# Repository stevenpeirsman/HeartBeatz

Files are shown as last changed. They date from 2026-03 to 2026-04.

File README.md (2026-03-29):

# HeartBeatz

**Portable WiFi CSI Sensing Demo Box** — presence detection, pose estimation, and vital signs monitoring using WiFi Channel State Information (CSI), BLE beacons, and mmWave radar.

HeartBeatz packages the [RuView](https://github.com/ruvnet/RuView) sensing platform into a self-contained, battery-powered appliance for client on-site demos. Power on, wait 30 seconds, and the 7" touchscreen walks you through node discovery and room calibration automatically.

---

## Architecture

```
┌─────────────────────────────────────────────────────────────────┐
│  MAIN BOX (MeLE N100 Mini PC)                                  │
│  ┌───────────────────────────────────────────────────────────┐  │
│  │ Docker                                                     │  │
│  │  ┌─────────────────────┐  ┌────────────────────────────┐  │  │
│  │  │ sensing-server      │  │ heartbeatz                  │  │  │
│  │  │ (Rust/Axum)         │  │ (Node.js)                   │  │  │
│  │  │ :3000 REST          │◄─│ :8080 UI + API              │  │  │
│  │  │ :3001 WebSocket     │  │ - Node discovery             │  │  │
│  │  │ :5005 UDP ingest    │  │ - BLE beacon tracking        │  │  │
│  │  └─────────────────────┘  │ - LD2410S radar reader       │  │  │
│  │                            │ - WebSocket hub → UI         │  │  │
│  │                            └────────────────────────────┘  │  │
│  └───────────────────────────────────────────────────────────┘  │
│  IHANFO 7" IPS Display (1024x600, Chromium Kiosk)              │
│  UGREEN 25,000mAh Power Bank                                   │
└────────────────────────┬────────────────────────────────────────┘
                         │ Ethernet (192.168.8.10)
              ┌──────────┴──────────┐
              │ GL.iNet MT3000      │
              │ Router (192.168.8.1)│
              │ SSID: HeartBeatz    │
              └──┬───┬───┬───┬─────┘
                 │   │   │   │  WiFi (192.168.8.x)
          ┌──────┘   │   │   └──────┐
          ▼          ▼   ▼          ▼
     ┌─────────┐┌─────────┐┌─────────┐┌─────────┐
     │ ESP32-S3││ ESP32-S3││ ESP32-S3││ ESP32-S3│
     │ Node 1  ││ Node 2  ││ Node 3  ││ Node 4  │
     │ + Radar ││ + Radar ││ + Radar ││ + Radar │
     │ + UPS   ││ + UPS   ││ + UPS   ││ + UPS   │
     └─────────┘└─────────┘└─────────┘└─────────┘
       CSI + radar data → UDP :5005 → sensing-server
```

## Hardware Bill of Materials

| Component | Model | Qty | Purpose |
|---|---|---|---|
| Mini PC | MeLE Quieter4C (N100, 16GB, 512GB) | 1 | Runs Docker, serves UI |
| Router | GL.iNet MT3000 (Beryl AX) | 1 | Private WiFi for ESP32 nodes |
| Display | IHANFO 7" IPS (HDMI, 1024x600) | 1 | Touchscreen kiosk UI |
| Power Bank | UGREEN 25,000mAh (140W USB-C PD) | 1 | Powers MeLE + display |
| Sensor Node | Heemol ESP32-S3 N16R8 DevKit | 4-5 | WiFi CSI collection |
| Node UPS | TECNOIOT 18650 UPS HAT | 4-5 | Battery backup per node |
| Batteries | 18650 Li-ion cells (3000mAh+) | 8-10 | 2 per node UPS |
| Radar | HLK-LD2410S (24GHz mmWave) | 4-5 | Secondary presence detection |
| BLE Beacons | ABN05 wristbands (nRF52810) | 5-10 | Patient/staff identification |

> **In a hurry?** See [QUICKSTART.md](QUICKSTART.md) for a condensed version. This README is the full reference.

## Quick Start (Demo Mode)

You can run HeartBeatz without any hardware. Demo mode generates realistic simulated data with three built-in scenarios (patient monitoring, fall detection, occupancy tracking).

```bash
# Clone the repository
git clone https://github.com/stevenpeirsman/HeartBeatz.git
cd HeartBeatz

# Start with Docker
docker compose up -d

# Open the UI
open http://localhost:8080
```

The system auto-detects that no ESP32 nodes are reachable and falls back to demo mode. You'll see a "DEMO MODE" banner in the UI with a scenario selector.

To force demo mode explicitly, set `DEMO_MODE=true` in `.env`.

## MeLE N100 Setup (Full Hardware)

Follow these steps in order when setting up the MeLE N100 for the first time.

### Step 1: Install Ubuntu

Install Ubuntu 22.04 LTS (Server or Desktop minimal) on the MeLE N100.

- Use a USB stick with the Ubuntu installer (Rufus or Balena Etcher to create it).
- During install: set hostname to `heartbeatz`, create user `heartbeatz`.
- Choose "Minimal installation" — the kiosk script installs everything else.

After install, connect via keyboard/monitor or SSH and update:

```bash
sudo apt update && sudo apt upgrade -y
```

### Step 2: Install Docker

```bash
# Install Docker
sudo apt install -y docker.io docker-compose
sudo systemctl enable docker
sudo usermod -aG docker heartbeatz

# Log out and back in for group change to take effect
exit
```

Verify Docker works:

```bash
docker run hello-world
```

### Step 3: Clone the Repo

```bash
cd /opt
sudo git clone https://github.com/stevenpeirsman/HeartBeatz.git
sudo chown -R heartbeatz:heartbeatz HeartBeatz
cd HeartBeatz
```

### Step 4: Configure the Network

Connect the MeLE to the GL.iNet router via Ethernet, then run:

```bash
sudo bash system/network-setup.sh
```

This assigns a static IP (`192.168.8.10`) on the router's network. Verify with:

```bash
ping 192.168.8.1    # Should reach the router
ip addr show        # Should show 192.168.8.10
```

### Step 5: Configure the GL.iNet Router

Log into the router admin panel at `http://192.168.8.1`:

1. Set the WiFi SSID to `HeartBeatz` and password to `heartbeatz2026`.
2. Set the WiFi channel to **6** (fixed — must match the ESP32 firmware).
3. Disable band steering and channel auto-selection.
4. Set the DHCP range to `192.168.8.100–192.168.8.199` (keeps `.10` reserved for MeLE).

### Step 6: Start the Services

```bash
cd /opt/HeartBeatz

# Build the Node.js container
docker compose build

# Pull the sensing server image
docker compose pull sensing-server

# Start everything
docker compose up -d

# Verify both containers are healthy
docker compose ps
docker compose logs -f   # Ctrl+C to stop watching
```

Open `http://192.168.8.10:8080` in a browser to verify the UI loads.

### Step 7: Install Kiosk Mode

Once the UI works in a browser, install the kiosk auto-boot service:

```bash
sudo bash system/install-kiosk.sh
```

This does the following:

- Installs X11, Chromium, and display utilities.
- Creates a systemd service (`heartbeatz-kiosk`) that starts on boot.
- Launches Chromium in fullscreen kiosk mode pointing at `http://localhost:3000/setup`.
- Disables desktop login managers (GDM, LightDM).
- Sets up auto-login for the `heartbeatz` user.

Reboot to test:

```bash
sudo reboot
```

The MeLE should boot directly into the HeartBeatz UI on the 7" display.

### Managing the Kiosk

```bash
# Check kiosk status
sudo systemctl status heartbeatz-kiosk

# View kiosk logs
sudo journalctl -u heartbeatz-kiosk -f

# Restart the kiosk (e.g., after a UI update)
sudo systemctl restart heartbeatz-kiosk

# Temporarily disable kiosk (for maintenance)
sudo systemctl stop heartbeatz-kiosk
```

## ESP32-S3 Firmware

Each sensor node runs custom firmware that collects WiFi CSI data and sends it to the sensing server over UDP.

### Prerequisites

Install [PlatformIO](https://platformio.org/install/cli):

```bash
pip install platformio
```

### Build and Flash

```bash
cd firmware

# Build the firmware
pio run

# Flash to a connected ESP32-S3 (USB-C)
pio run --target upload

# Open serial monitor to verify it connects
pio device monitor --baud 115200
```

### What to Expect on Boot

The ESP32 serial output should show:

1. WiFi connecting to SSID `HeartBeatz`...
2. Got IP `192.168.8.1xx`
3. Sending CSI frames to `192.168.8.10:5005` at 50 Hz
4. LED blinks: slow = connecting, solid = streaming, fast = error

### Firmware Configuration

Default values are compile-time flags in `firmware/include/heartbeatz_config.h` (set via `platformio.ini` build flags, **not** `.env`). The key settings:

| Setting | Default | Description |
|---|---|---|
| `HEARTBEATZ_WIFI_SSID` | `HeartBeatz` | Router WiFi SSID |
| `HEARTBEATZ_WIFI_PASS` | `heartbeatz2026` | Router WiFi password |
| `HEARTBEATZ_SERVER_IP` | `192.168.8.10` | MeLE IP (UDP target) |
| `HEARTBEATZ_UDP_PORT` | `5005` | Sensing server UDP port |
| `HEARTBEATZ_CSI_RATE_HZ` | `50` | CSI frame rate |
| `HEARTBEATZ_CHANNEL` | `6` | WiFi channel (must match router) |
| `HEARTBEATZ_RADAR_ENABLED` | `0` | Set to `1` if LD2410S is wired |
| `HEARTBEATZ_POWER_SAVE` | `0` | Set to `1` for battery mode (~10 Hz) |

These can also be overridden at runtime via NVS (Non-Volatile Storage) through the setup wizard.

### Wiring the LD2410S Radar (Optional)

If you attach an LD2410S radar module to a sensor node:

```
ESP32-S3          LD2410S
────────          ───────
GPIO 17 (TX)  →   RX
GPIO 18 (RX)  ←   TX
3.3V          →   VCC
GND           →   GND
```

Set `HEARTBEATZ_RADAR_ENABLED=1` in `platformio.ini` build flags before flashing.

## Configuration Reference

All configuration is in the `.env` file at the project root. Copy `.env` to `.env.local` for site-specific overrides.

### Network

| Variable | Default | Description |
|---|---|---|
| `HEARTBEATZ_IP` | `192.168.8.10` | MeLE static IP |
| `GATEWAY_IP` | `192.168.8.1` | Router IP |
| `SUBNET` | `192.168.8.0/24` | Network subnet |

### Sensing Server

| Variable | Default | Description |
|---|---|---|
| `CSI_SOURCE` | `auto` | `auto`, `esp32`, or `simulated` |
| `SENSING_HTTP_PORT` | `3000` | REST API port |
| `SENSING_WS_PORT` | `3001` | WebSocket port |
| `SENSING_UDP_PORT` | `5005` | ESP32 CSI UDP ingest port |
| `SENSING_TICK_MS` | `100` | Processing tick rate (ms) |

### Node Discovery

| Variable | Default | Description |
|---|---|---|
| `DISCOVERY_INTERVAL_MS` | `5000` | How often to scan for nodes |
| `NODE_TIMEOUT_MS` | `15000` | Mark node offline after this |
| `NODE_SUBNET` | `192.168.8.0/24` | Expected node subnet |

### BLE Beacons

| Variable | Default | Description |
|---|---|---|
| `BLE_ENABLED` | `false` | Enable BLE beacon scanning |
| `BLE_HCI_DEVICE` | `hci0` | Bluetooth adapter (`hci0` = built-in) |
| `BLE_UUID_FILTER` | *(empty)* | iBeacon UUID filter (empty = all) |
| `BLE_RSSI_THRESHOLD` | `-70` | In-room RSSI threshold (dBm) |

### LD2410S Radar

| Variable | Default | Description |
|---|---|---|
| `RADAR_ENABLED` | `false` | Enable radar reading |
| `RADAR_SERIAL_PORT` | *(auto)* | Serial port (auto-detected if empty) |
| `RADAR_BAUD_RATE` | `256000` | LD2410S baud rate |

### Demo Mode

| Variable | Default | Description |
|---|---|---|
| `DEMO_MODE` | `auto` | `true`, `false`, or `auto` (probe server) |
| `DEMO_SCENARIO` | `patient-monitoring` | Starting scenario |

Available scenarios: `patient-monitoring`, `fall-detection`, `occupancy-tracking`.

### Display & Logging

| Variable | Default | Description |
|---|---|---|
| `DISPLAY_WIDTH` | `1024` | Kiosk display width (px) |
| `DISPLAY_HEIGHT` | `600` | Kiosk display height (px) |
| `LOG_LEVEL` | `info` | `debug`, `info`, `warn`, `error` |

## Development

### Running Locally (Without Docker)

```bash
cd server
npm install
npm run dev     # Starts with --watch for auto-reload
```

The UI is served from `ui/` at `http://localhost:8080`. Without a sensing server running, demo mode activates automatically.

### Running Tests

```bash
cd server
npm test
```

Tests cover: config loading, node discovery polling, radar frame parsing, WebSocket event routing, simulator scenarios, and API endpoint validation.

### Project Structure

```
HeartBeatz/
├── docker-compose.yml      # Runs sensing-server + heartbeatz containers
├── .env                    # All configuration with defaults
├── server/                 # Node.js orchestration layer
│   ├── Dockerfile
│   ├── package.json
│   └── src/
│       ├── index.js        # Entry point — boots all subsystems
│       ├── config.js       # Environment + persistent state
│       ├── discovery.js    # Polls sensing server for ESP32 nodes
│       ├── ble-scanner.js  # iBeacon/Eddystone tracking (Linux)
│       ├── radar.js        # LD2410S mmWave UART reader
│       ├── simulator.js    # Demo mode data generator (3 scenarios)
│       ├── websocket.js    # WS hub — enriches + broadcasts to UI
│       └── routes/
│           └── api.js      # REST endpoints (health, nodes, beacons, etc.)
├── ui/                     # Kiosk touchscreen interface
│   ├── index.html          # Splash → Setup Wizard → Live Dashboard
│   ├── css/app.css
│   └── js/
│       ├── app.js          # State machine + WebSocket client
│       └── room-map.js     # Canvas room visualization (12 layers)
├── firmware/               # ESP32-S3 PlatformIO project
│   ├── platformio.ini
│   ├── partitions.csv
│   └── include/
│       └── heartbeatz_config.h
├── system/                 # Linux system setup scripts
│   ├── install-kiosk.sh    # Configures auto-boot Chromium kiosk
│   └── network-setup.sh    # Static IP on GL.iNet network
└── cadquery/               # 3D enclosure STEP files
```

## Boot Sequence

When the MeLE powers on, here's what happens:

1. **systemd** starts the `heartbeatz-kiosk` service.
2. **Docker Compose** starts `sensing-server` (Rust) and `heartbeatz` (Node.js).
3. The kiosk script waits up to 120 seconds for the sensing server health check.
4. **Chromium** launches in fullscreen kiosk mode at `http://localhost:3000/setup`.
5. The **Splash Screen** shows a progress bar while polling `/api/health`.
6. Once ready, the **Setup Wizard** starts node discovery (polling `/api/nodes`).
7. After nodes are found, the wizard runs a 10-second **room calibration**.
8. The **Live Dashboard** opens with real-time vital signs, room map, and beacon tracking.

If the sensing server is unreachable, the system falls into demo mode with simulated data.

## Troubleshooting

### No ESP32 Nodes Detected

- Verify the router WiFi SSID is exactly `HeartBeatz` (case-sensitive) and the channel is **6**.
- Check that the ESP32 got an IP: open the serial monitor (`pio device monitor`).
- Ensure the MeLE firewall allows UDP on port 5005: `sudo ufw status`.
- Check the sensing server logs: `docker compose logs sensing-server`.

### UI Shows "Connecting..." Indefinitely

- Verify both containers are running: `docker compose ps`.
- Check the heartbeatz container logs: `docker compose logs heartbeatz`.
- Test the API directly: `curl http://localhost:8080/api/health`.

### Demo Mode Activates When It Shouldn't

- The sensing server container may still be starting. Check its health: `docker compose ps`.
- Wait for the healthcheck to pass (up to 15 seconds after container start).
- Set `DEMO_MODE=false` in `.env` to force real mode (will show errors if server is down).

### Kiosk Display Issues

- If the display is blank, check `sudo systemctl status heartbeatz-kiosk`.
- The IHANFO display works over HDMI with no special drivers. Ensure the HDMI cable is connected before boot.
- For display resolution issues, verify `DISPLAY_WIDTH=1024` and `DISPLAY_HEIGHT=600` in `.env`.

### BLE Beacons Not Showing

- BLE is disabled by default. Set `BLE_ENABLED=true` in `.env`.
- BLE scanning requires host network mode. Uncomment `network_mode: host` in `docker-compose.yml`.
- Verify the Bluetooth adapter: `hcitool dev` (should show `hci0`).

### Radar Not Reading

- Radar is disabled by default. Set `RADAR_ENABLED=true` in `.env`.
- Uncomment the `devices` section in `docker-compose.yml` to pass through `/dev/ttyUSB0`.
- Check serial port: `ls /dev/ttyUSB*` or `ls /dev/ttyACM*`.

## License

Private project. Not for redistribution.

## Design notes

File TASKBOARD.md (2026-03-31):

# HeartBeatz Development Task Board
<!-- Single source of truth for all agent coordination -->
<!-- Updated by: architect (assigns), workers (status), reviewer (feedback) -->

## Active Sprint: Sprint 1 — Foundation & Infrastructure

**Sprint Goal:** Build feature extraction pipeline, ground truth system, adaptive baseline improvements, database layer, and admin module foundation. Establish engineering infrastructure for all accuracy and platform work.

**Sprint Start:** 2026-03-31
**Sprint End:** 2026-04-14

---

## Task Assignment Matrix

### ACC-01: Feature Extraction Pipeline (worker-alpha)

| Task ID | Title | Status | Branch | Priority | Est |
|---|---|---|---|---|-----|
| ACC-01-T1 | Implement subcarrier grouping into 8 logical bands (guard/pilot/data) | approved | feat/subcarrier-grouping | P0 | 2h |
| ACC-01-T2 | Add phase difference extraction with linear unwrapping | approved | feat/phase-extraction | P0 | 3h |
| ACC-01-T3 | Implement short-time FFT for Doppler motion classification (breathing 0.2-0.5Hz, walking 1-3Hz) | approved | feat/doppler-fft | P0 | 4h |
| ACC-01-T4 | Add statistical features: mean, variance, kurtosis, skewness, IQR, entropy per window | approved | feat/stat-features | P1 | 3h |
| ACC-01-T5 | Implement subcarrier correlation matrix with eigenvalue spread metric | approved | feat/corr-matrix | P1 | 3h |
| ACC-01-T6 | Build frame quality scorer (RSSI stability, timestamp jitter, packet loss) | approved | feat/frame-quality | P1 | 2h |
| ACC-01-T7 | Create feature vector serializer (JSON for SSE, CSV export for ML training) | approved | feat/feature-serializer | P1 | 2h |
| ACC-01-T8 | Add /api/v1/features endpoint returning current feature vectors per node | approved | feat/features-api | P1 | 1h |
| ACC-01-T9 | Add /api/v1/features/stream SSE endpoint at 5Hz | approved (merged with T8) | feat/features-api | P1 | 1h |

### ACC-03: Adaptive Baseline Calibration (worker-beta)

| Task ID | Title | Status | Branch | Priority | Est |
|---|---|---|---|---|-----|
| ACC-03-T1 | Implement multi-timescale baseline tracking (fast alpha=0.1/30s, medium alpha=0.01/5min, slow alpha=0.001/1hr) | approved | feat/multi-timescale-baseline | P0 | 3h |
| ACC-03-T2 | Add CUSUM environment change detection on per-subcarrier residuals | approved | feat/cusum-detection | P0 | 3h |
| ACC-03-T3 | Build automatic empty-room detection heuristic (variance < 1.2x baseline for >10min) | approved | feat/empty-room-detect | P0 | 2h |
| ACC-03-T4 | Implement baseline persistence to disk (save hourly + on shutdown, load on restart) | approved | feat/baseline-persist | P1 | 2h |
| ACC-03-T5 | Add recalibration event structured logging with shift magnitude and trigger type | in-review | feat/recal-logging | P1 | 1h |
| ACC-03-T6 | Create /api/v1/calibration/history endpoint returning last 100 recal events | in-review | feat/cal-history-api | P1 | 1h |
| ACC-03-T7 | Implement diurnal drift model (temperature correlation) | backlog | feat/diurnal-model | P2 | 3h |

### ACC-08: Ground Truth System (worker-gamma)

| Task ID | Title | Status | Branch | Priority | Est |
|---|---|---|---|---|-----|
| INFRA-01 | Add better-sqlite3 dependency and create database init module (auto-create tables on start) | approved | feat/sqlite-init | P0 | 2h |
| INFRA-02 | Create shared constants module: subcarrier count, frame sizes, feature names enum | approved | feat/shared-types | P0 | 1h |
| ACC-08-T1 | Build /api/v1/ground-truth POST endpoint (accepts {true_count, annotator, session_id}) | approved | feat/ground-truth-api | P0 | 2h |
| ACC-08-T2 | Build label collection web UI: large 0/1/2/3+ buttons, SSE live context, keyboard shortcuts | approved | feat/ground-truth-ui | P0 | 3h |
| ACC-08-T3 | Implement CSI-label alignment: match labels to nearest CSI frame by timestamp within 100ms | in-review | feat/label-alignment | P1 | 2h |
| ACC-08-T4 | Create automated evaluation pipeline: confusion matrix, precision/recall/F1, per-class breakdown | in-review | feat/eval-pipeline | P1 | 4h |
| ACC-08-T5 | Build /api/v1/evaluation/report endpoint returning latest accuracy metrics | approved | feat/eval-report-api | P1 | 1h |
| ACC-08-T6 | Implement labeling session management (start/stop/list sessions with metadata) | backlog | feat/label-sessions | P2 | 2h |
| ACC-08-T7 | Add CSV/JSON bulk export of labeled dataset via /api/v1/ground-truth/export | backlog | feat/gt-export | P2 | 1h |

### ADMIN: Node Management Module (worker-gamma)

| Task ID | Title | Status | Branch | Priority | Est |
|---|---|---|---|---|-----|
| ADMIN-01 | Create nodes database table (id, mac, name, ip, type, firmware_version, status, last_seen, position_x, position_y) | approved | feat/nodes-db | P0 | 2h |
| ADMIN-02 | Build /api/v1/nodes CRUD endpoints (list, get, create, update, delete) | approved | feat/nodes-crud-api | P0 | 3h |
| ADMIN-03 | Build node admin web UI: list nodes, add/edit name, delete, show status/firmware/last_seen | in-review | feat/nodes-admin-ui | P0 | 4h |
| ADMIN-04 | Integrate discovery service with nodes DB: auto-register discovered ESP32 nodes, update last_seen | approved | feat/nodes-discovery-sync | P1 | 2h |
| ADMIN-05 | Add firmware flash endpoint /api/v1/nodes/:id/flash (upload .bin, SSH to MeLE, esptool flash) | backlog | feat/nodes-firmware-flash | P1 | 4h |
| ADMIN-06 | Add node numbering/ordering system with drag-and-drop reorder in admin UI | backlog | feat/nodes-ordering | P2 | 2h |
| ADMIN-07 | Add node health check endpoint /api/v1/nodes/:id/ping (check reachability, get firmware version) | in-review | feat/nodes-health-api | P1 | 1h |

### SENSOR: LD2410S Radar Integration (worker-beta)

| Task ID | Title | Status | Branch | Priority | Est |
|---|---|---|---|---|-----|
| SENSOR-01 | Complete LD2410S UART parser for engineering mode frames (extend existing radar.js) | approved | feat/radar-parser | P0 | 3h |
| SENSOR-02 | Add radar data to SSE stream alongside CSI data (unified sensor event model) | in-review | feat/radar-sse | P1 | 2h |
| SENSOR-03 | Build radar configuration API: set detection gates, sensitivity thresholds, engineering mode toggle | backlog | feat/radar-config-api | P1 | 2h |
| SENSOR-04 | Implement CSI + radar fusion: use radar distance + energy as validation for CSI person detection | backlog | feat/csi-radar-fusion | P1 | 4h |
| SENSOR-05 | Add radar presence data to ground truth comparison (radar as secondary ground truth source) | backlog | feat/radar-ground-truth | P2 | 2h |
| SENSOR-06 | Create radar diagnostic dashboard: live distance/energy charts, detection state, gate visualization | backlog | feat/radar-dashboard | P2 | 3h |

### SENSOR: BLE Beacon Integration (worker-beta)

| Task ID | Title | Status | Branch | Priority | Est |
|---|---|---|---|---|-----|
| BLE-01 | Complete BLE scanner hcitool/hcidump integration for iBeacon parsing (extend existing ble-scanner.js) | approved | feat/ble-scanner-complete | P0 | 3h |
| BLE-02 | Add BLE beacon registry DB table (mac, uuid, major, minor, name, role, battery_level, last_seen) | backlog | feat/ble-registry-db | P1 | 2h |
| BLE-03 | Build beacon management admin UI: list beacons, assign names/roles (patient/staff/equipment) | backlog | feat/ble-admin-ui | P1 | 3h |
| BLE-04 | Implement RSSI-to-zone mapping: configurable RSSI thresholds per zone for proximity detection | backlog | feat/ble-zone-mapping | P1 | 3h |
| BLE-05 | Build CSI + BLE identity fusion: CSI detects "someone is here", BLE identifies "who is here" | backlog | feat/csi-ble-fusion | P1 | 4h |
| BLE-06 | Add BLE sighting data to SSE stream with identity resolution | backlog | feat/ble-sse | P2 | 1h |
| BLE-07 | Implement beacon battery monitoring with low-battery alerts | backlog | feat/ble-battery-alerts | P2 | 2h |

### DB: Database & Persistence Layer (worker-gamma)

| Task ID | Title | Status | Branch | Priority | Est |
|---|---|---|---|---|-----|
| DB-01 | Design unified SQLite schema: nodes, sensors, events, labels, evaluations, metrics, sessions | approved | feat/db-schema | P0 | 3h |
| DB-02 | Implement database migration system (version-tracked schema changes) | approved | feat/db-migrations | P1 | 2h |
| DB-03 | Build event storage: all detection events persisted with timestamp, node, count, confidence, features hash | in-review | feat/event-storage | P1 | 2h |
| DB-04 | Add metrics storage: hourly aggregates of accuracy, detection rate, false positive rate, latency | backlog | feat/metrics-storage | P1 | 2h |
| DB-05 | Create /api/v1/metrics endpoint: query accuracy trends, compare algorithm versions, time-range filter | backlog | feat/metrics-api | P1 | 2h |
| DB-06 | Implement data retention policy: raw events (30 days), aggregates (1 year), configurable via env vars | backlog | feat/data-retention | P2 | 2h |
| DB-07 | Add improvement tracking table: version, algorithm_config, accuracy_metrics, timestamp, notes | backlog | feat/improvement-tracking | P1 | 2h |
| DB-08 | Build /api/v1/improvements endpoint: log each algorithm change with before/after accuracy metrics | backlog | feat/improvements-api | P2 | 1h |

### UX: Frontend Dashboard & Visualization (worker-alpha)

| Task ID | Title | Status | Branch | Priority | Est |
|---|---|---|---|---|-----|
| UX-01 | Create main dashboard shell: responsive layout with sidebar nav, header, content area (HTML/CSS/JS) | backlog | feat/dashboard-shell | P0 | 4h |
| UX-02 | Build real-time overview panel: per-node person count, EMA, variance, confidence badges, trend sparklines | backlog | feat/overview-panel | P0 | 3h |
| UX-03 | Create zone/floor plan view: SVG overlay with colored zones, occupancy counts, click for zone detail | backlog | feat/floorplan-view | P1 | 5h |
| UX-04 | Build node status panel: list all ESP32 nodes, LD2410S radars, BLE scanners with health indicators | backlog | feat/node-status-panel | P1 | 2h |
| UX-05 | Create CSI feature heatmap v2: improved layout from dev-heatmap, add feature vector visualization | backlog | feat/heatmap-v2 | P1 | 3h |
| UX-06 | Build accuracy tracking dashboard: line charts of accuracy over time, confusion matrix visualization | backlog | feat/accuracy-dashboard | P1 | 3h |
| UX-07 | Create alert panel: live alerts for wandering, dwell-time, low battery, node offline, accuracy drop | backlog | feat/alert-panel | P2 | 3h |
| UX-08 | Add dark mode toggle and responsive mobile/tablet layout | backlog | feat/responsive-dark | P2 | 2h |
| UX-09 | Build settings page: configure thresholds, node positions, zone boundaries, alert rules | backlog | feat/settings-page | P2 | 4h |

### KPI: Hospital ED Metrics & Analytics (worker-gamma)

| Task ID | Title | Status | Branch | Priority | Est |
|---|---|---|---|---|-----|
| KPI-01 | Implement zone dwell-time tracker: per-zone timers with configurable alert thresholds | backlog | feat/dwell-time-tracker | P1 | 3h |
| KPI-02 | Build door-to-triage time estimator: detect entry zone → triage zone transition, compute duration | backlog | feat/door-to-triage | P1 | 3h |
| KPI-03 | Implement patient throughput counter: zone transitions per hour, daily totals, rolling averages | backlog | feat/throughput-counter | P1 | 2h |
| KPI-04 | Add LWBS (left without being seen) detection: entry zone dwell > threshold then exit without treatment zone visit | backlog | feat/lwbs-detection | P2 | 3h |
| KPI-05 | Build ED analytics dashboard: door-to-triage, dwell times, throughput, occupancy trends, LWBS rate | backlog | feat/ed-analytics | P2 | 5h |
| KPI-06 | Implement shift handoff report: auto-generated summary at shift change with zone status, pending patients, alerts | backlog | feat/shift-handoff | P2 | 3h |
| KPI-07 | Add nurse call integration hooks: webhook receiver for nurse call events, correlate with location data | backlog | feat/nurse-call-hooks | P3 | 3h |
| KPI-08 | Build bed management status: auto-detect room occupancy state (empty/occupied/cleaning) from CSI patterns | backlog | feat/bed-management | P2 | 4h |

### ACC-02: ML Classifier (worker-alpha) — Sprint 2+

| Task ID | Title | Status | Branch | Priority | Est |
|---|---|---|---|---|-----|
| ACC-02-T1 | Design labeled data collection protocol: annotation schema, activity types, collection UI integration | backlog | feat/ml-data-protocol | P1 | 2h |
| ACC-02-T2 | Build training data pipeline: stream features to labeled SQLite dataset, support manual annotation | backlog | feat/ml-training-pipeline | P1 | 4h |
| ACC-02-T3 | Install ONNX Runtime for Node.js on MeLE N100, verify performance | backlog | feat/onnx-setup | P1 | 2h |
| ACC-02-T4 | Train Random Forest classifier (200 trees, max_depth=12) with feature importance analysis | backlog | feat/ml-random-forest | P1 | 5h |
| ACC-02-T5 | Implement A/B comparison mode: run threshold-based + ML in parallel, log both, compare in dashboard | backlog | feat/ml-ab-compare | P1 | 3h |
| ACC-02-T6 | Build model evaluation framework: confusion matrix, per-class P/R/F1, ROC curves, auto-report | backlog | feat/ml-eval-framework | P2 | 3h |
| ACC-02-T7 | Implement online learning: high-confidence predictions auto-label, nightly retrain trigger | backlog | feat/ml-online-learning | P2 | 4h |
| ACC-02-T8 | Add model versioning: store model artifacts, config, metrics per version, rollback support | backlog | feat/ml-versioning | P2 | 2h |

### ACC-06: Breathing & Vital Signs (worker-alpha) — Sprint 2+

| Task ID | Title | Status | Branch | Priority | Est |
|---|---|---|---|---|-----|
| ACC-06-T1 | Implement Butterworth IIR bandpass filter bank: breathing (0.1-0.5Hz), heart (0.8-2.0Hz) | backlog | feat/bandpass-filters | P1 | 3h |
| ACC-06-T2 | Add harmonic rejection via comb filter to prevent breathing rate doubling | backlog | feat/harmonic-rejection | P1 | 2h |
| ACC-06-T3 | Implement multi-subcarrier voting: median of per-band estimates, confidence = agreement ratio | backlog | feat/vital-voting | P1 | 2h |
| ACC-06-T4 | Add motion gating: suspend vital estimation when gross motion > 5x breathing threshold | backlog | feat/motion-gating | P1 | 1h |
| ACC-06-T5 | Build signal quality metric (0-1): SNR, autocorrelation prominence, subcarrier agreement | backlog | feat/vital-quality | P1 | 2h |
| ACC-06-T6 | Implement Kalman filter for continuous breathing rate tracking | backlog | feat/vital-kalman | P2 | 3h |

### ACC-09: State Machine & Temporal Smoothing (worker-beta) — Sprint 2+

| Task ID | Title | Status | Branch | Priority | Est |
|---|---|---|---|---|-----|
| ACC-09-T1 | Design state machine model: EMPTY/OCCUPIED_1/2/3+/TRANSITIONING with transition constraints | backlog | feat/state-machine-model | P1 | 2h |
| ACC-09-T2 | Implement HMM smoother: emission from ML confidence, transition matrix encoding physical plausibility | backlog | feat/hmm-smoother | P1 | 4h |
| ACC-09-T3 | Add configurable hysteresis: different thresholds for entering vs leaving occupied state | backlog | feat/hysteresis | P1 | 2h |
| ACC-09-T4 | Implement transition event emitter: {from_state, to_state, timestamp, confidence, duration_ms} | backlog | feat/transition-events | P1 | 1h |
| ACC-09-T5 | Build anti-flicker median filter (window=7) combined with state machine | backlog | feat/anti-flicker | P1 | 1h |

### ACC-04: Spatial Fusion (worker-alpha) — Sprint 3+

| Task ID | Title | Status | Branch | Priority | Est |
|---|---|---|---|---|-----|
| ACC-04-T1 | Implement node topology model: node positions in room coordinates, config file schema | backlog | feat/node-topology | P1 | 2h |
| ACC-04-T2 | Build probabilistic occupancy grid: 1m x 1m cells, P(occupied | CSI observations) per cell | backlog | feat/occupancy-grid | P1 | 5h |
| ACC-04-T3 | Implement Bayesian sensor fusion across nodes with temporal motion prior | backlog | feat/bayesian-fusion | P1 | 4h |
| ACC-04-T4 | Add zone entry/exit event detection with 5-second hysteresis | backlog | feat/zone-events | P1 | 2h |
| ACC-04-T5 | Build graceful degradation on node failure: widen uncertainty, reweight remaining nodes | backlog | feat/node-degradation | P2 | 2h |
| ACC-04-T6 | Add spatial consistency cross-validation between nodes | backlog | feat/spatial-consistency | P2 | 2h |

### ACC-07: Interference Rejection (worker-beta) — Sprint 3+

| Task ID | Title | Status | Branch | Priority | Est |
|---|---|---|---|---|-----|
| ACC-07-T1 | Implement spectral interference detector: flag frames with >25% subcarrier deviation | backlog | feat/interference-detect | P1 | 3h |
| ACC-07-T2 | Build adaptive frame quality filter combining RSSI, amplitude distribution, phase coherence | backlog | feat/quality-filter | P1 | 3h |
| ACC-07-T3 | Add static multipath estimation during calibration, subtract from live observations | backlog | feat/multipath-subtract | P1 | 3h |
| ACC-07-T4 | Implement channel change detection (distinguish channel hop from human movement) | backlog | feat/channel-detect | P2 | 2h |
| ACC-07-T5 | Build interference statistics dashboard widget | backlog | feat/interference-stats | P2 | 2h |

### TECH-DEBT: Code Quality Cleanup (any worker with capacity)

| Task ID | Title | Status | Branch | Priority | Est |
|---|---|---|---|---|-----|
| DEBT-01 | Extract shared _ema() helper from multi-timescale.js and cusum.js into shared/math-utils.js | in-review | feat/shared-ema | P1 | 0.5h |
| DEBT-02 | Remove dead `activeThreshold` variable in empty-room.js (line ~193) | in-review | feat/cleanup-empty-room | P1 | 0.5h |
| DEBT-03 | Add pino logging to empty-room.js and doppler.js on state transitions | in-review (empty-room.js done, doppler.js → worker-alpha) | feat/add-logging | P1 | 1h |
| DEBT-04 | Verify ground-truth.html transport: WebSocket vs SSE — standardize to match project conventions | in-review | feat/gt-transport-fix | P1 | 1h |

**Architect assignment (2026-03-31):** DEBT-01 + DEBT-02 → worker-beta (owns calibration modules); DEBT-03 → split: empty-room.js logging → worker-beta, doppler.js logging → worker-alpha; DEBT-04 → worker-gamma (owns ground-truth UI). Workers: pick these up as gap-fillers between main tasks — they're fast wins that clean up reviewer-flagged issues.

### RTLS: Zone & Flow Management — Sprint 3+

| Task ID | Title | Status | Branch | Priority | Est |
|---|---|---|---|---|-----|
| RTLS-01-T1 | Build floor plan upload/calibration: web UI for PNG/SVG upload, scale setting, origin point | backlog | feat/floorplan-upload | P1 | 3h |
| RTLS-01-T2 | Implement zone drawing tool: canvas polygon drawing, edit, assign properties (name, type, color) | backlog | feat/zone-drawing | P1 | 5h |
| RTLS-01-T3 | Build node-to-zone assignment: drag nodes onto floor plan, store mapping in DB | backlog | feat/node-zone-assign | P1 | 3h |
| RTLS-01-T4 | Implement zone adjacency auto-detection from polygon boundaries | backlog | feat/zone-adjacency | P2 | 2h |
| RTLS-02-T1 | Implement per-zone occupancy state machine using ACC-09 per zone | backlog | feat/zone-state | P1 | 3h |
| RTLS-02-T2 | Build event stream: ZONE_ENTER, ZONE_EXIT, COUNT_CHANGE, DWELL_ALERT via SSE | backlog | feat/zone-events-sse | P1 | 2h |
| RTLS-02-T3 | Implement anonymous journey tracking: aggregate flow stats per zone without individual attribution | backlog | feat/anon-journey | P2 | 3h |
| RTLS-02-T4 | Build historical flow replay: slider to replay zone occupancy over past periods | backlog | feat/flow-replay | P2 | 4h |

### GDPR: Privacy & Compliance — Sprint 2+

| Task ID | Title | Status | Branch | Priority | Est |
|---|---|---|---|---|-----|
| GDPR-01 | Implement audit logging: immutable append-only log of all API access with hash chain | backlog | feat/audit-log | P1 | 3h |
| GDPR-02 | Build data anonymization layer: hash all patient/person references with rotating salt | backlog | feat/anonymization | P1 | 2h |
| GDPR-03 | Implement right-to-erasure: delete all records for a given pseudonym across all tables | backlog | feat/data-erasure | P2 | 2h |
| GDPR-04 | Add data minimization configuration: toggle what data is collected/retained per privacy level | backlog | feat/data-minimization | P2 | 2h |

### INTEGRATION: External Systems — Sprint 4+

| Task ID | Title | Status | Branch | Priority | Est |
|---|---|---|---|---|-----|
| INT-01 | Design EHR adapter interface: abstract class with sendLocationEvent(), queryPatientContext() | backlog | feat/ehr-adapter | P1 | 2h |
| INT-02 | Implement HL7 FHIR adapter: map zone events to FHIR Location/Encounter resources | backlog | feat/fhir-adapter | P2 | 4h |
| INT-03 | Build event queue with retry: SQLite-backed persistent queue, exponential backoff | backlog | feat/event-queue | P1 | 3h |
| INT-04 | Create data export pipeline: hourly Parquet/CSV export for data warehouse | backlog | feat/data-export | P2 | 3h |
| INT-05 | Build MQTT broker integration for IoT interop (sensor data, alerts, commands) | backlog | feat/mqtt-broker | P2 | 3h |
| INT-06 | Add webhook dispatcher for external notifications (dwell alerts, count changes, zone events) | backlog | feat/webhook-dispatch | P2 | 2h |

---

## Agent Roles

### worker-alpha (Signal Processing & UX Specialist)
**Focus:** CSI signal processing, feature extraction, spectral analysis, frontend visualization
**Current Sprint:** ACC-01 (Feature Extraction) + start UX foundation
**Skills:** DSP, FFT, filtering, subcarrier analysis, HTML/CSS/JS dashboards

### worker-beta (Calibration, Sensors & Robustness Engineer)
**Focus:** Baseline management, LD2410S radar, BLE beacons, sensor fusion, environment adaptation
**Current Sprint:** ACC-03 (Adaptive Baseline) + SENSOR (LD2410S/BLE start)
**Skills:** Statistical methods, CFAR, UART protocols, BLE, sensor fusion

### worker-gamma (Infrastructure, Data & Admin Engineer)
**Focus:** Database, APIs, ground truth, evaluation, admin module, hospital KPIs
**Current Sprint:** ACC-08 (Ground Truth) + INFRA + ADMIN + DB foundation
**Skills:** REST APIs, SQLite, web UIs, testing frameworks, data pipelines

---

## Review Queue

**⚡ Architect Note (2026-03-31 evening):** 6 items pending review — this is the sprint's primary bottleneck. Reviewer should process in the priority order below. Items are ordered by dependency chain: ACC-03-T4 and ADMIN-03 unblock nothing directly but validate persistence and admin foundations; ACC-08-T3/T4/T5 form a dependency chain (alignment → evaluator → eval-api). SENSOR-01 can be reviewed independently.

**Recommended review order:** ACC-03-T4 → SENSOR-01 → ADMIN-03 → ACC-08-T3 → ACC-08-T4 → ACC-08-T5

| Task ID | Branch | Worker | Review Status | Reviewer Notes |
|---|---|---|---|---|
| INFRA-02 | feat/shared-types | worker-alpha | **approved** | Clean foundation. Excellent docs with physical meaning/units. Frozen objects for immutability. 30 tests pass. Suggestion: add @enum annotations to band labels. |
| ACC-01-T1 | feat/subcarrier-grouping | worker-alpha | **approved** | Well-written pure functions. groupSubcarriers correctly validates + computes per-band/cross-band stats. Note: slice() in groupSubcarriers allocates per band per frame — acceptable at 8×7 elements on N100 but flag if profiling shows pressure. 22 tests pass. |
| ACC-01-T2 | feat/phase-extraction | worker-alpha | **approved** | **Excellent work.** Outstanding physics-based docs. unwrapPhase handles NaN gaps correctly. fitLinearPhase uses Bessel-corrected residualStd with n-2 (correct for 2-param model). wrapToPi handles arbitrary 2π multiples. 32 tests pass with comprehensive edge cases. |
| ACC-03-T1 | feat/multi-timescale-baseline | worker-beta | **approved** | Solid design. Sigmoid blending is elegant — weights sum to 1.0 at all interpolation points. State persistence clean. Rate-limiting good for N100. 19 tests pass. Minor: _ema() duplicated in cusum.js — extract to shared utility when convenient. |
| ACC-03-T2 | feat/cusum-detection | worker-beta | **approved** | Textbook two-sided CUSUM with proper references (Page 1954, Lucas & Crosier 1982). Channel voting robust against single-subcarrier glitches. FIR headstart, adaptive running std via MAD estimator (sqrt(π/2)) correct. Float64Array good for perf. 25 tests pass. Same _ema() duplication note. |
| INFRA-01 | feat/sqlite-init | worker-gamma | **approved** | Solid singleton pattern. WAL mode, foreign keys, busy_timeout all correct. Migration in transaction for atomicity. _resetDbSingleton for testing is good practice. inMemory mode for test isolation. 10 tests pass. Suggestion: add verbose_errors pragma for better debugging in dev. |
| DB-01 | feat/db-schema | worker-gamma | **approved** | Unified schema covers all planned modules (7 tables + 6 indexes). Version tracking via user_version is clean. Index choices match expected query patterns. Schema is embedded in INFRA-01's db/index.js — good single-file approach for PoC. |
| ACC-08-T1 | feat/ground-truth-api | worker-gamma | **approved** | Clean REST API following project conventions ({ok, data} responses). Good input validation in POST /labels: checks session exists AND is active, validates true_count range. Correct HTTP status codes (201 create, 400 validation, 404 not found, 409 conflict). Pagination support. 19 tests pass with good coverage of happy/error paths. |
| ACC-08-T2 | feat/ground-truth-ui | worker-gamma | **approved** | Well-structured labeling UI. Large touch-friendly buttons, keyboard shortcuts (0-3, S, E), live CSI context sidebar, label history. Session management flow is complete. CSS-only animations for feedback. Matches dev-heatmap.html aesthetic. Note: uses WebSocket but task description says SSE — verify which transport is correct for live context (not a blocker, both work). |
| ADMIN-01 | feat/nodes-db | worker-gamma | **approved** | Nodes table schema is complete: all specified columns present, MAC uniqueness enforced, REAL types for position coords, created_at/updated_at with datetime defaults. Part of DB-01 unified schema. 9 tests pass including constraint enforcement. |
| ADMIN-02 | feat/nodes-crud-api | worker-gamma | **approved** | Full CRUD with proper validation: MAC format regex, duplicate detection (409), partial update via dynamic SQL builder, allowed-fields whitelist prevents injection. Consistent with project API conventions. Note: PUT dynamic SQL builder constructs query from allowed list — safe pattern. |
| ACC-03-T3 | feat/empty-room-detect | worker-beta | **approved** | Well-designed Schmitt-trigger hysteresis. Clean sliding window with 10% transient spike tolerance for HVAC. State persistence via getState/restoreState. Excellent JSDoc with CFAR reference. 31 tests pass. Minor: `activeThreshold` (line 193) is computed but unused — isQuiet always uses varianceRatioThreshold; hysteresis is correctly handled in _evaluateState() so not a bug, just dead code — remove it. `_observations.shift()` in while loop is O(n) but acceptable at ≤720 entries. Suggestion: add pino logging on state transitions. |
| ACC-01-T3 | feat/doppler-fft | worker-alpha | **approved** | **Excellent work.** Pure-JS radix-2 FFT with no external deps — ideal for N100 portability. Hann window caching smart for hot-path. Clean pure function / stateful class separation. Doppler bands with physical descriptions are exemplary. 52 tests with known-signal verification. Circular buffer in DopplerAnalyzer handles wrap correctly. 52×64-pt FFT ≈ 0.2ms — well within budget. Classification thresholds well-chosen for 8-bit I/Q. Suggestion: add pino logging to DopplerAnalyzer for state transitions; consider exposing per-subcarrier spectra for debugging. |
| ADMIN-03 | feat/nodes-admin-ui | worker-gamma | **changes-requested** | CRUD, MAC validation, keyboard shortcuts all correct. Two fixes needed: (1) Font family mismatch — uses 'Courier New' instead of 'SF Mono', 'Fira Code', 'Consolas' matching dev-heatmap.html; update line 20. (2) Toast name bug — when creating node without name, toast shows "undefined" instead of MAC; fix line 708 to use `data.name \|\| macInput.value`. |
| ACC-03-T4 | feat/baseline-persist | worker-beta | **approved** | **Excellent work.** Production-ready persistence with correct atomic write (temp+rename), per-module error isolation, version-checked loading, and staleness detection. Immutable DEFAULT_CONFIG, fallback logger, diagnostic getStatus(). 41 tests cover full cycle, module failures, corrupted files, version mismatches, stale state. Suggestion: extract MODULE_KEYS as a constant (line 375) for future extensibility. |
| ACC-08-T3 | feat/label-alignment | worker-gamma | **changes-requested** | Functionally correct alignment with good UTC handling and tolerance boundaries. Three fixes needed: (1) Misleading docs — header claims "binary search" but implementation uses two ORDER BY+LIMIT queries; update to "indexed range queries". (2) Missing input validation — add sessionId format check and maxDeltaMs ≥ 0 validation. (3) Extract repeated strftime format string '%Y-%m-%d %H:%M:%f' (appears 8 times) to a module-level constant TIMESTAMP_FORMAT. Also: add a SQLite datetime format test (space-separated, no 'Z') and strengthen confidence filter test (verify filtered < unfiltered). |
| ACC-01-T4 | feat/stat-features | worker-alpha | **approved** | **Excellent work.** All formulas correct: Fisher-Pearson skewness with n/((n-1)(n-2)) correction, Bessel-corrected variance, linear interpolation quantile matching NumPy, Shannon entropy normalized to [0,1]. Pure functions throughout. Named constants (ENTROPY_BINS=16, MIN_WINDOW=8, MAX_WINDOW=400). Circular buffer efficient (~16KB memory). Export aliases (statMean/statVariance) avoid conflicts with amplitude.js. 68 tests with known-answer verification. |
| SENSOR-01 | feat/radar-parser | worker-beta | **approved** | **Excellent work.** Production-ready LD2410S parser. Byte offsets verified correct against protocol. Multi-layer frame validation: header presence, minimum length, 128-byte sanity check, tail verification, payload size. Variable gate counts (0-8) handled with proper boundary checks. Optional light sensor/output pin fields correct. Named constants throughout (FRAME_HEADER, FRAME_TAIL, MAX_GATES=9, GATE_WIDTH_CM). Buffer overflow protection at 1024 bytes. Exported pure helpers + frame builders for testing. Sub-millisecond parsing suitable for 20Hz on N100. 56 tests cover basic, engineering, robustness, mixed-mode, helpers. |
| ACC-08-T4 | feat/eval-pipeline | worker-gamma | **changes-requested** | Core evaluation math is correct and validated against sklearn equivalents — confusion matrix, precision/recall/F1, macro/weighted averages all verified. Zero-division protection present. 36 tests with known-answer verification. Two fixes needed: (1) Add input validation — `sessionId` should be checked for presence/format before querying. (2) Multi-session ID storage uses comma-joined string (line 480) which is ambiguous if IDs contain commas; refactor to JSON array. Minor: document rounding+clamping behavior at line 73-74. |
| ACC-08-T5 | feat/eval-report-api | worker-gamma | **approved** | Clean REST API with 5 well-defined endpoints. Input validation correct (sessionIds array check, numeric ID validation, limit defaults). Consistent {ok, data/error} responses with proper HTTP status codes (200/400/404/500). Pino child logger with module context. JSON parsing for confusion_json with null handling. Delegates correctly to evaluator.js. Follows all project conventions. |
| BLE-01 | feat/ble-scanner-complete | worker-beta | **approved** | **Excellent work.** Correct iBeacon parsing (Apple 0x004C, type 0x0215, 16-byte UUID, big-endian major/minor, signed TX power) and Eddystone-UID (0xFEAA, frame type 0x00, 10-byte namespace, 6-byte instance). HCI advertising report decoding with LE→BE MAC reversal. Multi-line hex accumulation robust with overflow protection (4096 chars). Pure helpers exported for testing. Unified sensor event model matches project architecture decision. 42 tests cover all parsers, frame accumulation, overflow, identity resolution, stale pruning. |
| ACC-03-T5 | feat/recal-logging | worker-beta | **pending review** | Structured pino logging for recalibration events. TriggerType enum (scheduled/cusum_shift/empty_room/manual/startup). Shift magnitude computed as relative |new-old|/old. Ring buffer (default 100 events) for API. Severity-based log levels (warn >50%, info >10%, debug <10%). getSummary() for aggregate stats. 17 tests pass. |
| ACC-03-T6 | feat/cal-history-api | worker-beta | **pending review** | REST API for calibration history. GET /history with limit/nodeId/triggerType query filters. GET /summary for aggregate stats. Input validation on triggerType against TriggerType enum. Follows project API conventions ({ok, data/error}). 9 tests pass. |
| DEBT-01 | feat/shared-ema | worker-beta | **pending review** | Extracted shared ema() to shared/math-utils.js, refactored multi-timescale.js and cusum.js to import from shared module instead of duplicating _ema(). All 54 tests across both modules still pass. Also added clamp() utility. 10 math-utils tests pass. |
| DEBT-02 | feat/cleanup-empty-room | worker-beta | **pending review** | Removed dead `activeThreshold` variable from empty-room.js. Was computed but never used — hysteresis correctly handled in _evaluateState(). 31 empty-room tests pass. |
| DEBT-03 | feat/add-logging | worker-beta | **pending review** | Added optional pino logger to EmptyRoomDetector constructor. Logs state transitions (empty↔occupied) with context (variance, threshold, confidence). Logger is optional — null-safe checks throughout. worker-beta portion only (empty-room.js); doppler.js logging assigned to worker-alpha. |
| ACC-03-T5 | feat/recal-logging | worker-beta | **approved** | Clean structured logging with severity-based levels (debug <10%, info 10-50%, warn >50% shift). Frozen TriggerType enum (5 types). Ring buffer with filtering and summary aggregation. Safe baseline handling (guards division by zero). Sequential ID for deduplication. 17 tests cover shift magnitude calculations, zero baseline edge case, ring buffer FIFO, filtering, summary stats. |
| ACC-03-T6 | feat/cal-history-api | worker-beta | **approved** | Clean Express router with GET /history (filters: nodeId, triggerType, limit clamped to [1,100]) and GET /summary. Input validation with proper 400 responses for invalid triggerType. Consistent {ok, data/error} format. 9 tests cover all filters, limit enforcement, invalid input, empty data. |
| DEBT-01 | feat/shared-ema | worker-beta | **approved** | Clean extraction of reusable EMA and clamp utilities. Excellent JSDoc with Brown 1963 reference and half-life examples. 10 tests with mathematical precision checks (1e-10 tolerance), convergence verification, boundary conditions. Properly addresses reviewer-flagged duplication between multi-timescale.js and cusum.js. |
| DEBT-02 | feat/cleanup-empty-room | worker-beta | **approved** | Dead code properly removed — no activeThreshold variable present. Hysteresis correctly handled via varianceRatioThreshold and reoccupyRatioThreshold in _evaluateState(). All 31 existing tests pass. Addresses reviewer-flagged issue from cycle 2. |
| DEBT-03 | feat/add-logging | worker-beta + worker-alpha | **approved** | **worker-beta:** Structured pino logging on EmptyRoomDetector state transitions with rich context (from/to, confidence, quietFraction, quietDurationMs, observationCount). Graceful null-check. Backward-compatible. **worker-alpha:** Module-level pino logger on DopplerAnalyzer motion_class_change events with debug on reset. Both address reviewer-flagged issue from cycle 2. All existing tests pass. |
| DB-02 | feat/db-migrations | worker-gamma | **approved** | **Excellent design.** Version tracked via PRAGMA user_version (clean, no extra table). Sequential append-only migrations with per-migration transactions for atomicity. V2 handles ALTER TABLE safely with column existence check. Migration registry with metadata. Comprehensive utilities: runMigrations, getCurrentVersion, getMigrationStatus, validateSchema. Correct refactoring of db/index.js to delegate schema work. 21 tests cover fresh migration, incremental upgrade, idempotency, data preservation, all table/index creation. |
| ACC-01-T5 | feat/corr-matrix | worker-alpha | **approved** | Mathematically sound implementation. Bessel-corrected covariance, symmetric matrix, Pearson correlation clamped to [-1,1]. Power method eigenvalue solver deterministic with appropriate convergence (MAX_ITER=20, EPSILON=1e-8 for 8×8). Trace-based smallest eigenvalue estimation with MAX_SPREAD=1000 cap. Rich correlation features (mean/min/max off-diagonal, adjacent, edge-DC). O(n·64) per window, ~8KB memory per node. 46 tests with known-answer verification (identity, rank-1, known 2×2 eigenvalues). |
| ACC-01-T6 | feat/frame-quality | worker-alpha | **approved** | Well-tuned quality scorer. RSSI stability (variance thresholds), timestamp jitter (CV-based), packet loss (16-bit seq wraparound handled), amplitude validity (70% subcarrier threshold). Weights sum to 1.0 (0.25+0.25+0.30+0.20). All sub-scores normalized to [0,1]. Named constants throughout. ~400B memory per node. 33 tests including wraparound edge case [65534,65535,0,1,2] → 0% loss. |
| ACC-01-T7 | feat/feature-serializer | worker-alpha | **approved** | Clean dual-format serialization. JSON (epoch-ms for SSE), CSV (ISO 8601 for ML). Precision tuned: PRECISION_STANDARD=4, PRECISION_HIGH=6. Column definitions frozen with Object.freeze(). Band arrays correctly flattened with prefixed naming (band_0_mean, band_1_variance, etc.). Column uniqueness enforced. Pure functions throughout. Round-trip serialization verified. 35 tests. |
| ACC-01-T8 | feat/features-api | worker-alpha | **approved** | Combined ACC-01-T8 (REST) and ACC-01-T9 (SSE) cleanly in one module. FeatureStore: Map-based O(1) lookup with MAC normalization to uppercase. SSE at 5Hz (200ms) with 30s keepalive, 5min idle timeout. Correct SSE headers (Content-Type, Cache-Control, X-Accel-Buffering). Node filtering via ?node= query param. Factory pattern with DI for logger and store. Cleanup prevents memory leaks. 14 tests. |
| ADMIN-04 | feat/nodes-discovery-sync | worker-gamma | **approved** | Well-designed EventEmitter bridge. Comprehensive MAC normalization (uppercase, raw 12-char hex, colon-separated, invalid → null). COALESCE for firmware prevents null overwrites. Manually-added nodes preserved (discovery_source stays 'manual'). Reconciliation marks missing nodes offline without auto-delete. Double-subscription prevention. Error resilience with try-catch in handlers. Parameterized SQL throughout. 21 tests cover lifecycle, registration, duplicates, MAC formats, offline marking, reconciliation, error resilience. |
| ACC-08-T3 | feat/label-alignment | worker-gamma | **pending review** | **Cycle 3 fixes:** (1) Updated header docs from "binary search" to "indexed range queries" matching actual implementation. (2) Added input validation: sessionId format check (regex), maxDeltaMs ≥ 0 validation with informative errors. (3) Extracted repeated strftime format to TIMESTAMP_FORMAT module constant (was hardcoded 8 times). (4) Added 8 new tests: input validation (6 tests), SQLite datetime format handling (1 test), confidence filter strength verification (1 test). Total: 31 tests pass (was 23). |
| ACC-08-T4 | feat/eval-pipeline | worker-gamma | **pending review** | **Cycle 3 fixes:** (1) Added sessionId validation in evaluateSession() and sessionIds array validation in evaluateMultipleSessions(). (2) Refactored multi-session ID storage from comma-joined string to JSON.stringify(sessionIds) — eliminates ambiguity if IDs contain commas. (3) Documented rounding+clamping behavior at buildConfusionMatrix lines 73-74 with explanation of why (ensemble averages, 3+ class mapping). All 36 existing tests pass. |
| ADMIN-03 | feat/nodes-admin-ui | worker-gamma | **pending review** | **Cycle 3 fixes:** (1) Fixed font family from 'Courier New' to 'SF Mono', 'Fira Code', 'Consolas' matching dev-heatmap.html. (2) Fixed toast name bug: create-node toast now references `data.name \|\| macInput.value` instead of potentially-undefined `name` variable. |
| DEBT-04 | feat/gt-transport-fix | worker-gamma | **pending review** | Converted ground-truth.html from WebSocket to SSE (EventSource). Was using `new WebSocket('/ws')` — now uses `new EventSource('/api/v1/features/stream')` matching project conventions (dev-heatmap.html uses EventSource, features API provides SSE at 5Hz). Added proper EventSource cleanup on session end. Auto-reconnect handled natively by EventSource. |
| DB-03 | feat/event-storage | worker-gamma | **pending review** | Promoted from backlog (DB-01 foundation approved). New event-storage.js module: storeEvent() with full input validation (node_id, predicted_count, confidence 0-1, algorithm enum). storeBatch() for high-throughput ingestion with transactional atomicity and MAX_BATCH_SIZE=500 guard. Query functions: getEventsByNode (with since/algorithm filters), getEventsInRange, getEventSummary (per-node aggregates), countEvents. pruneOldEvents() for data retention (default 30 days). Express route handler factories for GET/POST /api/v1/events. 35 tests cover single insert, batch, validation errors, queries, pruning, constants. |
| ADMIN-07 | feat/nodes-health-api | worker-gamma | **pending review** | Promoted from backlog (ADMIN-01/02 approved). New node-health.js module: tcpPing() checks TCP reachability with configurable timeout. fetchNodeInfo() retrieves firmware version from ESP32 /info HTTP endpoint using raw socket (no node-fetch dependency). checkNodeHealth() orchestrates: DB lookup → TCP ping → optional /info fetch → DB status update. pingAllNodes() bulk checks all nodes with IPs. Express router: GET /:id/ping (single node) and GET /ping/all (bulk). Proper error handling: 404 for unknown node, 422 for no IP. 13 tests cover TCP ping (reachable/unreachable/timeout), HTTP info parsing, DB integration, bulk ping, constants. |
| SENSOR-02 | feat/radar-sse | worker-beta | **pending review** | Promoted from backlog (all SENSOR P0s approved). New radar-sse.js module: toUnifiedEvent() adapter transforms RadarReading→unified event model {type:'radar-reading', source:'radar', timestamp, data}. RadarStore class: in-memory store with SSE client management, push/broadcast, basic+engineering latest tracking. Express router: GET /api/v1/radar (snapshot), GET /api/v1/radar/stream (SSE with ?mode=engineering filter), GET /api/v1/radar/stats. connectRadarToStore() bridge function wires RadarService→RadarStore with cleanup. Mounted in api-v1.js, wired in index.js with graceful shutdown. 30 tests pass: toUnifiedEvent (5), RadarStore (12), connectRadarToStore (6), constants (4), integration (3). |

---

## Architecture Decisions Log

| Date | Decision | Rationale | Decided By |
|---|---|---|---|
| 2026-03-31 | Use better-sqlite3 for all storage | Synchronous API, zero-config, fast, portable. Sufficient for PoC volumes (< 1M rows). | architect |
| 2026-03-31 | Feature vectors as JSON arrays in SSE stream | Compatible with existing SSE infrastructure, easy to consume in browser | architect |
| 2026-03-31 | Workers commit to feature branches, reviewer merges to main | Prevents conflicts, ensures code review before integration | architect |
| 2026-03-31 | Unified sensor event model: {type, source, timestamp, data} | CSI, radar, BLE all emit same event structure for clean fusion | architect |
| 2026-03-31 | Admin UI as separate HTML pages (same pattern as dev-heatmap.html) | Keep deployment simple, no build step, progressive enhancement | architect |
| 2026-03-31 | LD2410S connected via ESP32 UART, not directly to MeLE | ESP32 already has UART handling, keeps MeLE USB ports free | architect |
| 2026-03-31 | BLE beacons for identity, CSI for presence/activity, radar for validation | Each sensor's strength compensates others' weaknesses | architect |
| 2026-03-31 | Hospital KPI metrics derived from zone events, not raw sensor data | Clean separation of sensing layer and analytics layer | architect |
| 2026-03-31 | Extract shared math utilities (EMA, etc.) into shared/math-utils.js | Prevent duplication across calibration modules. Reviewer flagged _ema() in both multi-timescale.js and cusum.js — single source of truth reduces maintenance risk | architect |
| 2026-03-31 | Standardize on SSE for all live data streams (not WebSocket) | Project already uses SSE infrastructure; ground-truth UI should align. WebSocket adds a second protocol with no benefit for unidirectional push | architect |
| 2026-03-31 | P1 task promotion policy: promote all P1s in a work package once all P0s in that package are approved | Keeps workers unblocked. Day 1 cleared all P0s — workers need immediate next assignments | architect |
| 2026-03-31 | E2E integration test at review cycle 4 (after ~20 reviews) | Enough modules exist to test cross-module integration. Earlier E2E would test too little. Next E2E checkpoint: when ACC-08-T3/T4/T5 + ACC-03-T4 are approved (full ground-truth + persistence pipeline) | architect |
| 2026-03-31 | Tech-debt items assigned to module owners, treated as gap-fillers | Keeps main sprint velocity while resolving reviewer-flagged issues. Workers should pick up DEBT tasks when between main task assignments | architect |

---

## Blocked Items

| Task ID | Blocked By | Description | Unblock Action |
|---|---|---|---|
| (none currently) | | | |

---

## Completed Tasks

| Task ID | Title | Worker | Completed | Review Status |
|---|---|---|---|---|
| INFRA-02 | Create shared constants module: subcarrier count, frame sizes, feature names enum | worker-alpha | 2026-03-31 | approved (first try) |
| ACC-01-T1 | Implement subcarrier grouping into 8 logical bands | worker-alpha | 2026-03-31 | approved (first try) |
| ACC-01-T2 | Add phase difference extraction with linear unwrapping | worker-alpha | 2026-03-31 | approved (first try) |
| ACC-03-T1 | Implement multi-timescale baseline tracking (3-tier EMA) | worker-beta | 2026-03-31 | approved (first try) |
| ACC-03-T2 | Add CUSUM environment change detection on per-subcarrier residuals | worker-beta | 2026-03-31 | approved (first try) |
| INFRA-01 | Add better-sqlite3 database init module with WAL mode | worker-gamma | 2026-03-31 | approved (first try) |
| DB-01 | Design unified SQLite schema (7 tables + 6 indexes) | worker-gamma | 2026-03-31 | approved (first try) |
| ACC-08-T1 | Build ground truth REST API (sessions + labels CRUD) | worker-gamma | 2026-03-31 | approved (first try) |
| ACC-08-T2 | Build label collection web UI with keyboard shortcuts | worker-gamma | 2026-03-31 | approved (first try) |
| ADMIN-01 | Create nodes database table with MAC uniqueness | worker-gamma | 2026-03-31 | approved (first try) |
| ADMIN-02 | Build /api/v1/nodes CRUD endpoints with MAC validation | worker-gamma | 2026-03-31 | approved (first try) |
| ACC-03-T3 | Build automatic empty-room detection heuristic (Schmitt-trigger hysteresis) | worker-beta | 2026-03-31 | approved (first try) |
| ACC-01-T3 | Implement short-time FFT for Doppler motion classification | worker-alpha | 2026-03-31 | approved (first try) |
| ACC-03-T4 | Implement baseline persistence to disk (atomic write, per-module error isolation) | worker-beta | 2026-03-31 | approved (first try) |
| ACC-03-T5 | Add recalibration event structured logging with shift magnitude | worker-beta | 2026-03-31 | approved (first try) |
| ACC-03-T6 | Create /api/v1/calibration/history endpoint | worker-beta | 2026-03-31 | approved (first try) |
| SENSOR-01 | Complete LD2410S UART parser for engineering mode frames | worker-beta | 2026-03-31 | approved (first try) |
| BLE-01 | Complete BLE scanner hcitool/hcidump integration (iBeacon + Eddystone-UID) | worker-beta | 2026-03-31 | approved (first try) |
| ACC-01-T4 | Add statistical features (skewness, kurtosis, IQR, entropy per window) | worker-alpha | 2026-03-31 | approved (first try) |
| ACC-01-T5 | Implement subcarrier correlation matrix with eigenvalue spread | worker-alpha | 2026-03-31 | approved (first try) |
| ACC-01-T6 | Build frame quality scorer (RSSI stability, jitter, packet loss) | worker-alpha | 2026-03-31 | approved (first try) |
| ACC-01-T7 | Create feature vector serializer (JSON for SSE, CSV for ML) | worker-alpha | 2026-03-31 | approved (first try) |
| ACC-01-T8/T9 | Features REST API + SSE stream at 5Hz (combined in one module) | worker-alpha | 2026-03-31 | approved (first try) |
| ACC-08-T5 | Build /api/v1/evaluation/report endpoint | worker-gamma | 2026-03-31 | approved (first try) |
| ADMIN-04 | Integrate discovery service with nodes DB (auto-register, MAC normalization) | worker-gamma | 2026-03-31 | approved (first try) |
| DB-02 | Implement database migration system (version-tracked, transactional) | worker-gamma | 2026-03-31 | approved (first try) |
| DEBT-01 | Extract shared EMA helper into shared/math-utils.js | worker-beta | 2026-03-31 | approved (first try) |
| DEBT-02 | Remove dead activeThreshold variable in empty-room.js | worker-beta | 2026-03-31 | approved (first try) |
| DEBT-03 | Add pino logging to empty-room.js and doppler.js state transitions | worker-beta + worker-alpha | 2026-03-31 | approved (first try) |
| DEBT-04 | Verify ground-truth.html transport: standardize to SSE | worker-gamma | 2026-03-31 | pending review |
| DB-03 | Build event storage module (single/batch insert, queries, pruning) | worker-gamma | 2026-03-31 | pending review |
| ADMIN-07 | Add node health check endpoint (TCP ping, firmware fetch) | worker-gamma | 2026-03-31 | pending review |

---

## Quality Metrics

- Review cycle count: 3 (E2E test on every 4th — **next E2E: cycle 4**)
- Tasks reviewed: 32 (13 in cycles 1-2 + 19 in cycle 3)
- Approved first try: 29
- Changes requested: 3
  - ACC-08-T3 (label alignment): misleading docs, missing input validation, repeated magic string
  - ACC-08-T4 (eval pipeline): missing sessionId validation, unsafe comma-joined multi-session IDs
  - ADMIN-03 (nodes admin UI): font family mismatch with dev-heatmap.html, toast name bug
- Common issues (cumulative):
  - ~~`_ema()` helper duplicated~~ **RESOLVED by DEBT-01** (shared/math-utils.js)
  - ~~Dead code: `activeThreshold` in empty-room.js~~ **RESOLVED by DEBT-02**
  - ~~No pino logging in empty-room.js, doppler.js~~ **RESOLVED by DEBT-03**
  - ground-truth.html uses WebSocket but task spec says SSE — verify correct transport (not blocking)
  - **NEW:** Input validation gaps in ground-truth pipeline (alignment + evaluator) — sessionId format checks, parameter validation
  - **NEW:** Font inconsistency in admin UIs (admin-nodes.html uses Courier New, should match SF Mono/Fira Code stack)
- Test suite: 883/884 pass (1 pre-existing ota-manager.test.js failure)
- Notes: Cycle 3 was the largest review batch yet — 19 items across all 3 workers + tech debt. Quality remains exceptionally high: 16/19 approved first try. The 3 changes-requested items have minor-to-medium severity issues (no correctness bugs in core logic). worker-alpha delivered the complete feature extraction pipeline (statistics, correlation, quality, serializer, API+SSE) — all 6 modules approved first try with excellent math, pure functions, and comprehensive tests. worker-beta's sensor work is production-ready: LD2410S radar parser and BLE scanner both have thorough protocol handling and defensive parsing. worker-gamma's infrastructure work (migrations, discovery sync, eval API) is solid, but the ground-truth alignment/evaluation chain needs input validation hardening. All 4 tech-debt items from cycle 2 feedback are now resolved. Sprint 1 is nearing completion — only 3 items need fixes before the full pipeline is reviewable end-to-end.

---

## E2E Test Results

| Date | Cycle # | Tests Pass | API OK | SSE OK | UI OK | DB OK | Memory | Issues Found |
|---|---|---|---|---|---|---|---|---|
| (no tests yet) | | | | | | | | |

---

## Sprint Backlog Summary

| Sprint | Focus | Story Points | Tasks | Status |
|---|---|---|---|---|
| Sprint 1 | Foundation: Features + Baseline + Ground Truth + DB + Admin | ~65 SP | 30 done, 3 changes-requested, 5 backlog | Active (Day 1 EOD — review bottleneck cleared, 3 items need fixes) |
| Sprint 2 | ML Classifier + Vital Signs + State Machine + GDPR | ~55 SP | 23 tasks | Planned |
| Sprint 3 | Spatial Fusion + Interference + Zones + Radar/BLE Fusion | ~60 SP | 22 tasks | Planned |
| Sprint 4 | Dashboard + KPIs + Integrations + Analytics | ~55 SP | 18 tasks | Planned |
| Sprint 5 | Polish + E2E Testing + Deployment Hardening + Documentation | TBD | TBD | Planned |

---

## Next Sprint Planning (Sprint 2 Preview)

**Promote to ready when Sprint 1 P0 tasks complete:**
- ACC-02-T1 through ACC-02-T5 (ML Classifier foundation)
- ACC-06-T1 through ACC-06-T4 (Vital sign hardening)
- ACC-09-T1 through ACC-09-T3 (State machine)
- GDPR-01, GDPR-02 (Audit logging, anonymization)
- UX-01, UX-02 (Dashboard shell, overview panel)

**Hardware dependencies for Sprint 2:**
- LD2410S radar modules (on order) → SENSOR-01 through SENSOR-06
- BLE beacons (on order) → BLE-01 through BLE-07

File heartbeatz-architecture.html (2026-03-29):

# HeartBeatz System Architecture

Portable WiFi CSI Sensing Demo Appliance — Complete Technical Reference

Hardware

Software

Network

UI / Display

## System Overview

HeartBeatz is a self-contained, battery-powered demo appliance that demonstrates WiFi Channel State Information (CSI) sensing. It detects human presence, pose, movement, and vital signs using only WiFi radio signals — no cameras, wearables, or contact sensors needed.

Sensor

3× ESP32-S3

CSI capture @ 50Hz

→UDP :5005

Router

GL.iNet MT3000

192.168.8.1

→Ethernet

Server

Rust / Axum

MeLE N100

→WebSocket

Display

Three.js Observatory

VoCore 5" + Browser

## Hardware Components

🖥️

MeLE Overclock4C (N100)

Main Box

Dimensions: 131 × 81 × 18.3mm • Weight: 317.5g
Intel N100 (4C/4T, 3.4GHz burst), 16GB DDR5, 512GB NVMe
Ports: 2× USB 3.2, 1× USB-C, HDMI, 2× Gigabit Ethernet, 3.5mm audio
TDP: 6W (configurable), passive cooling, runs Ubuntu 22.04 + Docker

📡

GL.iNet MT3000 (Beryl AX)

Main Box

Dimensions: 120 × 83 × 34mm • Weight: 196g
MediaTek MT7981B, WiFi 6 (AX3000), 2.4GHz + 5GHz
Creates private network (SSID: HeartBeatz), DHCP server at 192.168.8.1
MeLE connects via Ethernet (static 192.168.8.10), ESP32 nodes via WiFi

🔋

UGREEN 25,000mAh Power Bank

Main Box

Dimensions: 155 × 54 × 51mm • Weight: 609g
USB-C PD 140W + USB-A outputs, powers MeLE (PD) + Router (USB-A 5V/2A)
Estimated runtime: ~4-5 hours (MeLE ~10W + Router ~5W + Display ~2W)

📺

VoCore 5" Touchscreen

Main Box

Dimensions: 119.3 × 68.7 × 3.6mm • Connection: USB-C (USB 2.0)
800×480 resolution, capacitive touch, shows Observatory UI
Note: NOT HDMI — connects via USB display adapter protocol. Factor USB port allocation.

📶

3× Heemol ESP32-S3 N16R8

Sensor Nodes

Dimensions: ~70 × 28 × 8mm • Weight: ~10g each
Xtensa LX7 dual-core 240MHz, 16MB Flash, 8MB PSRAM
WiFi 6 capable, runs ESP-IDF v5.2 firmware, CSI collection + edge processing
Placed around demo room (2-5m from subjects), connected to HeartBeatz WiFi

🔌

TECNOIOT 18650 UPS + 2× Cells

Per Sensor Node

UPS Board: 90 × 22 × 28.5mm • Cells: 18mm Ø × 65mm each
Provides regulated 5V output to ESP32 via USB, charge-while-run
2× 18650 cells ≈ 6,000-7,000mAh → ~8-12 hours runtime per node
Total per node: ~100 × 65 × 35mm assembled with battery box

## Key Specifications

Parameter | Value | Notes
CSI Frame Rate | 50 Hz max | 20ms rate limiter in firmware (CSI_MIN_SEND_INTERVAL_US)
CSI Frame Size | 356 bytes typical | 20-byte ADR-018 header + 336 bytes I/Q (3 ant × 56 sub × 2 bytes)
Binary Magic | 0xC5110001 | ADR-018 CSI frame identifier, little-endian
Network | 192.168.8.x private | Router DHCP, MeLE static .10, ESP32 nodes .100-.102
REST API | Port 3000 | Axum HTTP server, 40+ endpoints
WebSocket | Port 3001 | Real-time sensing updates + pose streaming
UDP Ingest | Port 5005 | Binary CSI frames from ESP32 nodes
Docker | Multi-arch | amd64 + arm64, single docker-compose up
Signal Pipeline | 9 stages | Hampel → Phase → Fresnel → BVP → FFT → Pose
Demo Scenarios | 12 built-in | Simulation mode, no hardware needed
Total Main Box Weight | ~1,122g | MeLE + Router + Power Bank (without enclosure)

# Data Flow

End-to-end path from WiFi radio to 3D visualization

## Primary Data Pipeline

1. Capture

WiFi CSI Callback

esp_wifi_set_csi_rx_cb

→I/Q data

2. Serialize

ADR-018 Frame

20-byte header + payload

→UDP :5005

3. Ingest

esp32_frame_handler

Parse + validate magic

→Channel

4. Process

Signal Pipeline

9-stage DSP

→Broadcast

5. Stream

WebSocket

SensingUpdate JSON

→WS :3001

6. Render

Observatory

Three.js + HUD

## ADR-018 Binary Frame Format

Every CSI frame from ESP32 follows this exact binary layout (little-endian):

Offset | Size | Field | Type | Description
0 | 4 | Magic | u32 LE | 0xC5110001 — identifies CSI frame
4 | 1 | Node ID | u8 | Sensor node identifier (0-255)
5 | 1 | Antennas | u8 | Number of RX antennas (typically 1 on ESP32-S3)
6 | 2 | Subcarriers | u16 LE | Number of OFDM subcarriers (56 typical)
8 | 4 | Frequency | u32 LE | Center frequency in MHz (e.g., 2437 for ch6)
12 | 4 | Sequence | u32 LE | Monotonic frame counter
16 | 1 | RSSI | i8 | Received signal strength (dBm)
17 | 1 | Noise Floor | i8 | Noise floor (dBm)
18 | 2 | Reserved | — | Zero-padded for alignment
20 | N | I/Q Data | i8[] | Raw CSI: pairs of [I, Q] per subcarrier per antenna

Typical frame: 20 + (1 antenna × 56 subcarriers × 2 bytes) = 132 bytes. With 3 antennas: 356 bytes.

## Additional Frame Types

Magic | Type | Source | Content
0xC5110002 | Edge Vitals | ESP32 edge processing | Presence, fall, breathing, HR, motion energy, person count
0xC5110004 | WASM Output | ESP32 WASM runtime | Custom events from user-deployed WASM modules

## CSI Source Modes

The CSI_SOURCE environment variable (or --source CLI arg) controls where data comes from:

Mode | Description | Use Case
auto | Probe UDP :5005 for ESP32 → fall back to Windows WiFi → fall back to simulation | Default: hardware when available, demo otherwise
esp32 | Listen on UDP :5005 for ADR-018 binary frames from ESP32 nodes | Production mode with real sensor hardware
wifi | Windows WiFi passive scanning via netsh, multi-BSSID pipeline | Laptop demo without ESP32 hardware
simulated | Generated synthetic CSI data — no hardware required | Development, testing, offline demos

# Software Stack

16-crate Rust workspace + ESP-IDF C firmware + Three.js/React UI

## Rust Workspace (v0.3.0)

The server is a Cargo workspace with 16 crates. Key dependencies: Axum 0.7, Tokio, ndarray, rustfft, tch (PyTorch bindings), ONNX Runtime.

wifi-densepose-sensing-server

Main binary: Axum HTTP/WS server, UDP listener, signal pipeline orchestration, 40+ REST endpoints

→ core, signal, nn, api, config, hardware, vitals, ruvector

wifi-densepose-core

Foundational types: CsiFrame, CsiMetadata, PoseEstimate, PersonPose, Keypoint (COCO-17)

wifi-densepose-signal

DSP pipeline: CsiProcessor, PhaseSanitizer, Hampel, Spectrogram, Fresnel, BVP, Features, Motion

→ core, ndarray, rustfft, num-complex

wifi-densepose-nn

Neural network inference: pose estimation model, ONNX Runtime + PyTorch backends

→ core, tch, ort, candle-core

wifi-densepose-api

API types, request/response schemas, serialization helpers

wifi-densepose-config

Configuration management: env vars, YAML, CLI args via clap

wifi-densepose-hardware

Hardware abstraction: serial port comms, pcap capture, device discovery

wifi-densepose-vitals

Vital signs: breathing rate (0.1-0.5Hz), heart rate (0.67-2.0Hz) extraction via spectral analysis

wifi-densepose-ruvector

RuVector v2.0.4 integration: graph min-cut subcarrier partitioning, attention-gated spectrogram, BVP attention

wifi-densepose-db

Data persistence: SQLx (Postgres/SQLite), Redis, recording storage

wifi-densepose-wasm

WebAssembly bindings for browser-based processing

wifi-densepose-mat

Matrix utilities, ndarray helpers, data loading (.npy)

wifi-densepose-train

Model training: epochs, batches, learning rate scheduling, early stopping, LoRA fine-tuning

wifi-densepose-cli

Command-line tool: record, train, evaluate, export commands

wifi-densepose-wifiscan

Windows WiFi scanning: netsh parsing, multi-BSSID pipeline

wifi-densepose-desktop

Desktop application wrapper (Tauri/native)

## Signal Processing Pipeline

Raw CSI I/Q data goes through 9 sequential processing stages before producing sensing results:

1

CSI Preprocessing

csi_processor.rs

Raw I/Q intake, complex number conversion, amplitude/phase extraction. Config: sampling_rate, window_size, overlap, noise_threshold.

2

Phase Sanitization

phase_sanitizer.rs

Phase unwrapping to remove 2π discontinuities from multi-path reflections. Configurable unwrapping method.

3

Hampel Filter

hampel.rs

Robust outlier removal using median + MAD (Median Absolute Deviation). Window=3, threshold=3.0σ. Returns filtered signal + outlier indices.

4

Spectrogram

spectrogram.rs

STFT time-frequency decomposition. Windows: Hann, Hamming, Blackman. Attention-gated noise suppression via RuVector min-cut graph partitioning.

5

Fresnel Zone Analysis

fresnel.rs

Physical model: ΔΦ = 4π·d/λ. Maps CSI amplitude variations to body displacement through Fresnel zone crossings. Validates breathing matches expected physical model.

6

Body Velocity Profile (BVP)

bvp.rs

STFT → frequency-to-velocity mapping (v = f_doppler × λ / 2). Scaled dot-product attention over STFT rows (RuVector). Config: window=128, hop=32, velocity_bins=64.

7

Feature Extraction

features.rs

Extracts: AmplitudeFeatures, PhaseFeatures, DopplerFeatures, PowerSpectralDensity, CorrelationFeatures (inter-antenna/subcarrier).

8

Motion Detection

motion.rs

Presence + motion scoring with configurable thresholds. Outputs: HumanDetectionResult (confidence, MotionScore), classifies absent/present_still/active.

9

Vital Signs Extraction

vital_signs.rs

FFT spectral analysis on rolling buffers. Breathing: 0.1-0.5 Hz (6-30 BPM). Heart rate: 0.67-2.0 Hz (40-120 BPM). Outputs with per-metric confidence scores.

## Key Data Structures

CsiFrame

idFrameIdUnique identifier

metadataCsiMetadataTimestamp, device, freq, antenna config

dataArray2<Complex64>[spatial_streams × subcarriers]

amplitudeArray2<f64>Amplitude matrix

phaseArray2<f64>Phase matrix

SensingUpdate (WebSocket broadcast)

msg_typeString"sensing_update"

timestampf64Unix epoch ms

sourceString"esp32" | "wifi:{ssid}" | "simulate"

nodesVec<NodeInfo>Per-node RSSI, position, CSI

featuresFeatureInfomean_rssi, variance, band powers

vital_signsOption<VitalSigns>BR, HR, confidences

personsOption<Vec<PersonDetection>>Tracked people + poses

signal_fieldSignalField20×20 spatial grid

PoseEstimate

personsVec<PersonPose>Detected people

confidenceConfidence0.0 - 1.0

latency_msf32Processing time

VitalSigns

breathing_rate_bpmOption<f64>Breaths per minute

heart_rate_bpmOption<f64>Beats per minute

breathing_confidencef64[0, 1]

heartbeat_confidencef64[0, 1]

signal_qualityf64[0, 1]

# Network Topology

Private isolated network — fully offline operation

## Network Diagram

Node 0

ESP32-S3

192.168.8.100

↘

Node 1

ESP32-S3

192.168.8.101

→WiFi

Router

GL.iNet MT3000

192.168.8.1

→Ethernet

Server

MeLE N100

192.168.8.10

→USB

Display

VoCore 5"

localhost:3000

## IP Address Plan

Device | IP Address | MAC (assigned) | Connection | Notes
GL.iNet MT3000 | 192.168.8.1 | Router default | — | DHCP server, DNS, gateway
MeLE N100 | 192.168.8.10 | Static lease | Ethernet (GbE) | Static IP via DHCP reservation
ESP32 Node 0 | 192.168.8.100 | DHCP lease | WiFi (2.4GHz) | node_id=0 in NVS
ESP32 Node 1 | 192.168.8.101 | DHCP lease | WiFi (2.4GHz) | node_id=1 in NVS
ESP32 Node 2 | 192.168.8.102 | DHCP lease | WiFi (2.4GHz) | node_id=2 in NVS
Demo laptop (optional) | 192.168.8.x | DHCP | WiFi (5GHz) | Alternative UI on laptop browser

## Port Map

Port | Protocol | Direction | Service | Description
3000 | HTTP | MeLE → clients | REST API + Static UI | Axum server: health, sensing, model, recording, training endpoints
3001 | WebSocket | MeLE → clients | Real-time stream | /ws/sensing (SensingUpdate), /api/v1/stream/pose (PoseData)
5005 | UDP | ESP32 → MeLE | CSI ingest | ADR-018 binary frames, magic 0xC5110001
8080 | HTTP | MeLE → clients | Python sensing UI | Alternative Python-based UI (docker-compose service)
8765 | WebSocket | MeLE → clients | Python WS | Python sensing server WebSocket
80 | HTTP | ESP32 → local | OTA + WASM upload | Per-node HTTP server for firmware updates and WASM module deployment

## WiFi Configuration

Parameter | Value
SSID | HeartBeatz (configurable on router)
Security | WPA2-PSK
2.4GHz Band | Used by ESP32 nodes for CSI capture
5GHz Band | Available for demo laptop connection (higher throughput, no interference)
CSI Channel | Auto-detect from AP, or NVS override, or Kconfig default (ch6)
Promiscuous Mode | Enabled on ESP32 for reliable CSI callbacks on all frames
Channel Hopping | Optional: channels 1/6/11/36/40/44, configurable dwell time (min 10ms)

# ESP32-S3 Firmware

ESP-IDF v5.2, C, ADR-018 compliant — runs on Heemol ESP32-S3 N16R8

## Boot Sequence (app_main)

The firmware initializes 12 subsystems in order. Each is fault-tolerant — failures log warnings but don't halt boot:

1

NVS Flash Init

Initialize non-volatile storage. Auto-erases on version mismatch.

2

Load NVS Config

nvs_config_load() — reads 30+ fields from NVS namespace "csi_cfg", falls back to Kconfig defaults.

3

WiFi STA Init

wifi_init_sta() — connects to HeartBeatz network, 10 retries, WPA2-PSK (or open if no password).

4

UDP Sender Init

stream_sender_init_with(target_ip, target_port) — opens UDP socket to MeLE, ENOMEM backoff 100ms.

5

CSI Collection

csi_collector_init() — enables promiscuous mode, registers CSI callback, configures LLTF/HTLTF/STBC, 50Hz rate limiter.

6

Edge Processing

edge_processing_init() — configurable tier (0-3), presence/fall thresholds, vital sign window (256 samples).

7

OTA Server

ota_update_init_ex() — HTTP server for firmware updates. Shares httpd_handle with WASM upload.

8

WASM Runtime

wasm_runtime_init() — WASM3 interpreter for user-deployed sensing modules. Periodic on_timer() callback (default 1s).

9

mmWave Sensor

mmwave_sensor_init() — auto-detect radar sensor on UART. Optional complementary sensing. Graceful skip if absent.

10

Swarm Bridge

swarm_bridge_init() — connects to Cognitum Seed (if URL configured). Heartbeat + ingest intervals.

11

Power Management

power_mgmt_init(duty_cycle) — configurable duty cycle 0-100%. Manages sleep/wake for battery life.

12

Display Task

display_task_start() — AMOLED display (if CONFIG_DISPLAY_ENABLE). Shows status on node's local display.

## NVS Configuration (nvs_config_t)

30+ runtime-configurable fields, stored in NVS namespace "csi_cfg". Set via provision.py CLI tool.

### Network Settings

Field | Default | Description
wifi_ssid | Kconfig | WiFi SSID to connect to
wifi_password | Kconfig | WiFi password (empty = open)
target_ip | Kconfig | UDP target (MeLE IP)
target_port | 5005 | UDP target port
node_id | Kconfig | Node identifier (0-255)

### Channel Hopping (ADR-029)

Field | Default | Description
channel_hop_count | 1 | 1 = single-channel (no hop)
channel_list[] | [ch6] | Up to 6 channels
dwell_ms | 50 | Time per channel (min 10ms)
tdm_slot_index | 0 | Time-division slot
tdm_node_count | 1 | Total nodes in TDM

### Edge Processing (ADR-039)

Field | Default | Description
edge_tier | 2 | Processing tier (0=off, 3=full)
presence_thresh | 0.0 | 0 = auto-calibrate
fall_thresh | 15.0 | Fall detection threshold
vital_window | 256 | Samples for vital analysis
vital_interval_ms | 1000 | Vital signs update rate
top_k_count | 8 | Top-K subcarrier selection
power_duty | 100 | Power duty cycle (0-100%)

### MAC Filter (ADR-060)

Field | Default | Description
filter_mac[6] | unset | Only process frames from this MAC
filter_mac_set | false | Whether filter is active
csi_channel | 0 | 0 = auto-detect from AP

## CSI Collector Detail

The CSI callback fires on every WiFi frame received in promiscuous mode (100-500+ times/sec). Rate limiting caps UDP output to 50Hz:

// Rate-limit: 20ms = 50Hz max send rate
#define CSI_MIN_SEND_INTERVAL_US  (20 * 1000)

// CSI config enables all LTF types for maximum subcarrier data
wifi_csi_config_t csi_config = {
    .lltf_en = true,           // Legacy Long Training Field
    .htltf_en = true,          // HT Long Training Field
    .stbc_htltf2_en = true,    // STBC HT-LTF2
    .ltf_merge_en = true,      // Merge LTF types
    .channel_filter_en = false, // Raw, unfiltered
};

// Promiscuous filter: management + data frames
filter_mask = WIFI_PROMIS_FILTER_MASK_MGMT | WIFI_PROMIS_FILTER_MASK_DATA;

## Source Files

File | Lines | Purpose
main.c | 290 | Boot sequence, subsystem orchestration
csi_collector.c | 421 | CSI callback, ADR-018 serialization, channel hopping
stream_sender.c | 117 | UDP socket, ENOMEM backoff
nvs_config.c | 333 | 30+ config fields, NVS read/write
edge_processing.c | — | On-device presence, fall, vital signs
ota_update.c | — | HTTP firmware update server
wasm_runtime.c | — | WASM3 interpreter + timer
power_mgmt.c | — | Sleep/wake duty cycling
mmwave_sensor.c | — | Optional radar sensor
swarm_bridge.c | — | Cognitum Seed connectivity

# Ports & APIs

Complete REST API reference — 40+ endpoints on Axum

Health Sensing Pose Model Recording Training WebSocket

### Health & Info Endpoints

Method | Path | Handler | Description
GET | / | info_page | Landing page with server info
GET | /health | health | Basic health check
GET | /health/health | health_system | Detailed system health
GET | /health/live | health_live | Liveness probe (for Docker/K8s)
GET | /health/ready | health_ready | Readiness probe
GET | /health/version | health_version | Version and build info
GET | /health/metrics | health_metrics | Prometheus-style metrics
GET | /api/v1/info | api_info | API info + capabilities
GET | /api/v1/status | health_ready | Alias for readiness
GET | /api/v1/metrics | health_metrics | Alias for metrics

### Sensing Endpoints

Method | Path | Handler | Description
GET | /api/v1/sensing/latest | latest | Latest SensingUpdate frame (JSON)
GET | /api/v1/vital-signs | vital_signs_endpoint | Current vital signs (BR, HR, confidence)
GET | /api/v1/edge-vitals | edge_vitals_endpoint | Edge-computed vitals from ESP32 nodes
GET | /api/v1/wasm-events | wasm_events_endpoint | Events from ESP32 WASM modules
GET | /api/v1/stream/status | stream_status | Current stream state + connected clients

### Pose Endpoints

Method | Path | Handler | Description
GET | /api/v1/pose/current | pose_current | Current pose estimate (COCO-17 keypoints)
GET | /api/v1/pose/stats | pose_stats | Pose detection statistics
GET | /api/v1/pose/zones/summary | pose_zones_summary | Per-zone occupancy summary

### Model Management Endpoints

Method | Path | Handler | Description
GET | /api/v1/model/info | model_info | Active RVF model metadata
GET | /api/v1/model/layers | model_layers | Model layer architecture
GET | /api/v1/model/segments | model_segments | DensePose body segments
GET | /api/v1/model/sona/profiles | sona_profiles | Available SONA profiles
POST | /api/v1/model/sona/activate | sona_activate | Activate a SONA profile
GET | /api/v1/models | list_models | List available models
GET | /api/v1/models/active | get_active_model | Currently loaded model
POST | /api/v1/models/load | load_model | Load a model into memory
POST | /api/v1/models/unload | unload_model | Unload active model
DELETE | /api/v1/models/{id} | delete_model | Delete a stored model
GET | /api/v1/models/lora/profiles | list_lora_profiles | LoRA fine-tuning profiles
POST | /api/v1/models/lora/activate | activate_lora_profile | Activate LoRA adapter

### Recording Endpoints

Method | Path | Handler | Description
GET | /api/v1/recording/list | list_recordings | List saved recordings
POST | /api/v1/recording/start | start_recording | Start recording CSI data
POST | /api/v1/recording/stop | stop_recording | Stop recording
DELETE | /api/v1/recording/{id} | delete_recording | Delete a recording

### Training & Adaptive Endpoints

Method | Path | Handler | Description
GET | /api/v1/train/status | train_status | Current training status
POST | /api/v1/train/start | train_start | Start model training
POST | /api/v1/train/stop | train_stop | Stop training
POST | /api/v1/adaptive/train | adaptive_train | Train adaptive classifier
GET | /api/v1/adaptive/status | adaptive_status | Adaptive classifier state
POST | /api/v1/adaptive/unload | adaptive_unload | Unload adaptive model

### WebSocket Endpoints

Path | Port | Handler | Protocol
/ws/sensing | 3001 | ws_sensing_handler | Subscribe to broadcast → receives SensingUpdate JSON frames in real-time
/api/v1/stream/pose | 3001 | ws_pose_handler | Pose-specific stream. Sends: connection_established, pose_data. Receives: ping/pong
/ws/train/progress | 3001 | ws_train_progress | Training progress: epoch, batch, loss, PCK, OKS, LR, phase

### WebSocket Message Format (/ws/sensing)

{
  "msg_type": "sensing_update",
  "timestamp": 1711547823.456,
  "source": "esp32",
  "tick": 4521,
  "nodes": [{ "id": 0, "rssi": -42, "csi_amplitude": [...] }],
  "features": { "mean_rssi": -45.2, "variance": 12.8, "motion_band_power": 0.34 },
  "vital_signs": { "breathing_rate_bpm": 16.2, "heart_rate_bpm": 72.0, "breathing_confidence": 0.87 },
  "signal_field": { "width": 20, "height": 20, "values": [...] },
  "persons": [{ "id": 1, "position": [2.1, 0, 1.5], "motion_score": 0.6 }]
}

# UI & Visualization

Three.js Observatory — immersive real-time sensing visualization

## Observatory Scene

The primary visualization is a WebGL 3D scene rendered with Three.js. It shows wireframe human figures in a virtual room, with WiFi signal overlays and real-time vital signs HUD.

### Scene Setup

Element | Detail
Room | 6m wide with grid, wireframe edges, reflective floor
Camera | Perspective FOV 50°, position (6, 5, 8), auto-orbit
Lighting | 5-light system: ambient, hemisphere, key, fill, rim
Post-processing | Bloom, vignette, grain, chromatic aberration
Quality | 3 adaptive levels based on FPS
Router model | 3 antennas + LED indicator at (-4, 0.92, -3)

### Figure Rendering

Feature | Detail
Pool size | 4 figures max (configurable)
Skeleton | 17 COCO keypoints + 16 bone cylinders
Bone taper | Thicker at torso (0.12), thinner at limbs (0.04-0.07)
Aura glow | Sphere around each figure
Breathing pulse | ±0.1m amplitude modulation per joint
Trail particles | 200 particles, age and fade

### HUD Elements

Panel | Content
Left: Vitals | HR (color-coded: green 60-100, amber 50-60/100-130, red <50/>130), BR, confidence bars
Right: Signal | RSSI dBm, variance, motion level, person count dots
Top bar | Source badge (demo/ws), scenario selector, FPS, settings gear
Bottom | 80-point RSSI sparkline canvas

### Visual Effects

Effect | Detail
WiFi waves | 5 concentric spheres (0.8-4.8m radius), expand + fade
Dot-matrix mist | 800 shader particles following body shape
Signal field | 20×20 floor grid, color-mapped signal strength

## Keyboard Controls

Key | Action
A | Toggle autopilot camera orbit
D | Cycle to next demo scenario
F | Toggle FPS counter
S | Open/close settings dialog
Space | Pause/resume demo playback

## Visual Presets

Preset | Style | Bloom | Wire Color
Foundation | Default balanced | 0.08 | #00d878 (green)
Cinematic | High bloom, heavy vignette | 1.2 | —
Minimal | Clean, low bloom | 0.3 | Neon
Neon | Extreme bloom, chromatic | 2.5 | Bright
Medical | Professional cyan | — | #00ccff (cyan)

## Demo Scenarios (12 Built-in)

#1

Empty Room

Environmental noise, 2.4GHz microwave interference, HVAC cycling, day/night RSSI drift

environment

#2

Single Breathing

Breathing ~16 BPM, HRV (heart rate variability), respiratory sinus arrhythmia

vital_trend, cardiac_detail

#3

Two Walking

Figure-8 and ellipse paths, collision avoidance, phone pause behavior

person_match, tracking

#4

Fall Event

Pre-fall stumble (3-5s), impact spike, micro-movements, shock HR elevation

impact_detection, recovery_analysis

#5

Sleep Monitoring

Supine with micro-breathing, position shifts, sleep stage markers

sleep_stage, breathing_quality

#6

Intrusion Detect

Rapid unauthorized entry, presence spike, door sensor correlation

zone_breach, alert_trigger

#7

Gesture Control

Arm raises, sweeps, hand waves with pose transitions, DTW similarity

gesture_phase, dtw_similarity

#8

Crowd Occupancy

4 people at desks, complex multiplex signals, occupancy estimation

occupancy_count, spatial_clustering

#9

Search & Rescue

Through-wall survivor detection, weak signal, slow micro-movements

mat_mode_active, through_wall_distance

#10

Elderly Care

Gait analysis for fall risk, slower walking, periodic sitting

gait_metrics, fall_risk_score

#11

Fitness Tracking

High-intensity exercise, rep counting, stand→crouch→stand cycles

exercise_type, rep_count

#12

Security Patrol

Multi-zone presence detection, sustained walking patrols

zone_occupancy, patrol_timing

## Pose Fusion Engine

Separate module combining video (webcam) + WiFi CSI for enhanced pose estimation:

Component | Purpose
VideoCapture | Webcam stream, canvas overlay for skeleton
CsiSimulator | 52 subcarriers × 56 time-window, simulated CSI
CnnEmbedder | 128-dim embeddings from each modality
FusionEngine | Weighted blend: 70% video / 30% CSI (configurable)
PoseDecoder | Fused embedding → 17 COCO keypoints

# Enclosure Design

Verified component dimensions — Bambu Lab H2D, PETG, Fusion 360 parametric

## Component Dimensions (Verified)

MeLE Overclock4C (N100)

131 × 81 × 18.3 mm

317.5g

Passive cooling, needs bottom ventilation. 2× GbE on one side, USB/HDMI on other.

GL.iNet MT3000

120 × 83 × 34 mm

196g

Built-in antennas, USB-C power. Needs ventilation for heat.

UGREEN 25,000mAh

155 × 54 × 51 mm

609g

Heaviest component. Button + LED indicators on one end. USB-C PD + USB-A ports.

VoCore 5" Touchscreen

119.3 × 68.7 × 3.6 mm

~80g (est.)

USB-C connection (NOT HDMI!). Mounts on enclosure lid or side panel. Touch-capable.

ESP32-S3 DevKitC-1

70 × 28 × 8 mm

~10g

USB-C for power/programming. Antenna at one end — keep unobstructed.

TECNOIOT 18650 UPS + Cells

~100 × 65 × 35 mm assembled

~120g (with 2× cells)

UPS board: 90×22×28.5mm. Each 18650: 18mm Ø × 65mm. Parallel in battery box.

## Main Box — Internal Layout (Top View)

## Sensor Node — Internal Layout (Top View)

## Enclosure Design Parameters (Fusion 360)

Parameter | Main Box | Sensor Node | Notes
External dims | 210 × 175 × 65mm | 120 × 75 × 42mm | 5mm wall thickness
Wall thickness | 3mm | 2.5mm | PETG structural
Corner radius | 5mm | 4mm | Exterior corners
Vent holes | Bottom grid + side slots | Antenna end open | Passive airflow
Display cutout | 119.5 × 69mm | — | VoCore on lid, 0.1mm tolerance
USB port cutout | 12 × 6mm | 12 × 6mm | USB-C access for debug/charge
Lid attachment | M3 heat-set inserts × 4 | Snap-fit clips × 2 | Main box: screwed, nodes: tool-free
Material | PETG | PETG | Bambu Lab H2D, 0.2mm layer height
Infill | 20% gyroid | 15% gyroid | Balance of strength and weight
Print orientation | Lid up (no supports) | Lid up (no supports) | Bottom surface is print bed face

## Weight Budget

Component | Weight | Cumulative
UGREEN Power Bank | 609g | 609g
MeLE N100 | 317.5g | 926.5g
GL.iNet MT3000 | 196g | 1,122.5g
VoCore Display | ~80g | ~1,202g
Cables + connectors | ~50g | ~1,252g
PETG enclosure (est.) | ~120g | ~1,372g

Sensor nodes: ~140g each (ESP32 + UPS + cells + enclosure). Total system with 3 nodes: ~1.8 kg.

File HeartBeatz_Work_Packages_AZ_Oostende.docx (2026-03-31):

HeartBeatz

WiFi CSI Indoor Sensing Platform

Comprehensive Work Package Document

AZ Oostende Emergency Department RTLS

Deep Analysis | Gap Assessment | Development Roadmap

Version 1.0 — 31 March 2026

Prepared by: HeartBeatz Engineering

# Table of Contents

# Executive Summary

This document provides a comprehensive development roadmap for the HeartBeatz WiFi CSI indoor sensing platform, specifically scoped to address the requirements of AZ Oostende's Emergency Department RTLS proof-of-concept. It contains three interconnected sections:

- Part A: Deep analysis mapping current HeartBeatz capabilities against all 16 AZ Oostende user stories, identifying gaps and required development
- Part B: Ten precision-focused work packages designed to elevate person detection accuracy from proof-of-concept level to production-grade reliability
- Part C: Six platform work packages that build the RTLS infrastructure required to deliver the clinical use cases AZ Oostende needs

The total development effort is estimated at approximately 140 story points across 8 sprints (16 weeks), with critical-path items front-loaded in Sprints 1-4. The accuracy improvement work packages (Part B) run in parallel with the platform development (Part C), converging in Sprint 5-6 for integrated testing.

# Part A: Capability Analysis and Gap Assessment

## Current Platform Capabilities

HeartBeatz is a WiFi CSI-based indoor sensing platform built on ESP32-S3 microcontrollers and a Node.js processing bridge. The current implementation (v3) provides the following capabilities:

Capability | Current Implementation
CSI Collection | ESP32-S3 firmware collecting 802.11n CSI frames at 20Hz via custom ADR-018 binary protocol with I/Q data, MAC addressing, and sequence numbering
Person Detection | Threshold-based binary presence detection using amplitude variance with EMA smoothing (alpha=0.002) and calibration baseline
Person Counting | Variance-based person count estimation (0-5) using linear scaling with noise penalty and multi-node weighted fusion
Breathing Estimation | Autocorrelation-based breathing rate estimation from CSI micro-Doppler (0.1-0.5 Hz band)
Baseline Calibration | Rolling recalibration using CFAR-inspired 10th-percentile noise floor tracking with damped updates every 30 seconds
Real-time Visualization | Developer heatmap with per-subcarrier amplitude display, variance tracking, and SSE streaming at 5Hz
Multi-node Support | Concurrent processing of multiple ESP32 nodes with weighted fusion and node health monitoring
API | REST endpoints for health, calibration, heatmap data, and SSE streaming
Deployment | Docker Compose with auto-restart, deployment scripts for MeLE N100 mini PC (SSH-based)
Enclosures | Parametric CadQuery 3D models for SMA antenna box and button box (STEP export for Fusion 360)

## Requirement-by-Requirement Gap Analysis

The following table maps each AZ Oostende requirement to the current HeartBeatz capability, identifying the gap and required development work.

Requirement | Status | Current Capability | Gap / Development Needed
US-1: Tag Prep & Activation at Intake | Gap | No tag/wearable management system exists. CSI is tagless by design. | If tags required: tag lifecycle API, activation workflow. If tagless: patient registration endpoint with zone assignment.
US-2: Auto Time Registration at Triage | Partial | Person count detection with timestamps exists. No triage-specific zone mapping. | Zone-aware detection: map ESP32 nodes to physical zones (triage, waiting, treatment). Timestamp event logging per zone transition.
US-3: Auto Location Updates on Movement | Partial | Multi-node fusion detects presence. No room-to-room transition tracking. | Transition detection algorithm, zone graph model, movement event stream, location history persistence.
US-4: Auto Interaction Registration | Gap | No caregiver-patient proximity detection. | Dual-entity CSI fingerprinting, interaction event model, duration tracking, role-based attribution.
US-5: Tag Lifecycle Management | Gap | Not applicable (tagless). ESP32 node health monitoring exists. | If hybrid approach: BLE tag battery/hygiene tracking API. For CSI: node health dashboard with firmware OTA.
US-7: Wandering Patient Alerts | Gap | No geofencing or boundary detection. | Zone boundary model, dwell-time rules engine, alert routing (webhook/MQTT), configurable thresholds per zone.
US-10: Real-time Dashboard for Flowmanagers | Partial | Dev heatmap exists (subcarrier-level). Basic person count display. | Production dashboard with floor plan overlay, zone occupancy, patient flow visualization, wait-time indicators.
US-14: Wait-time Alerts | Gap | No dwell-time tracking or alerting. | Per-zone dwell timer, configurable alert thresholds, escalation rules, notification channels (email, SMS, dashboard).
US-16: Sub-room Positioning | Gap | Room-level presence only. No sub-room (bed-level) resolution. | Multi-antenna triangulation, CSI fingerprint database per bed position, ML classifier for sub-room localization.
Real-time Overview (all units) | Gap | Single-node or multi-node view. No department-wide aggregation. | Multi-zone aggregation service, department topology model, cross-unit dashboard, historical analytics.
OASIS/KWS Integration | Gap | No EHR/EPD integration. | HL7 FHIR adapter, KWS/NexuzHealth API client, OASIS webhook receiver, patient ID mapping layer.
Data Warehouse (Fabric/PowerBI) | Gap | No data export or warehouse integration. | Event data pipeline (Kafka/MQTT to warehouse), PowerBI dataset definitions, historical query API.
GDPR / Privacy by Design | Partial | CSI is inherently privacy-preserving (no cameras, no personal data in RF signals). | Data retention policies, anonymization layer for any PII, consent management, DPIA documentation, audit logging.
Multi-technology Hybrid | Gap | WiFi CSI only. | BLE beacon integration layer, UWB anchor support, sensor fusion engine combining CSI + BLE + UWB signals.

Summary: 0 Implemented | 4 Partial | 10 Gap — out of 14 total requirements assessed

# Part B: Accuracy Improvement Work Packages

These ten work packages form a systematic engineering program to elevate HeartBeatz person detection from proof-of-concept to production-grade accuracy. They are ordered by dependency and priority, with critical-path items in Sprints 1-2 establishing the foundation for subsequent improvements.

## Sprint Roadmap Overview

Sprint | Work Packages | Story Points
Sprint 1 | ACC-01 Feature Extraction, ACC-03 Adaptive Baseline, ACC-08 Ground Truth System | 29 SP
Sprint 2 | ACC-02 ML Classifier (start), ACC-06 Breathing Hardening, ACC-09 State Machine | 34 SP
Sprint 3 | ACC-02 ML Classifier (cont), ACC-04 Spatial Fusion (start), ACC-07 Interference Rejection | 34 SP
Sprint 4 | ACC-02 ML Classifier (finish), ACC-04 Spatial Fusion (cont), ACC-05 Fingerprinting (start) | 39 SP
Sprint 5 | ACC-05 Fingerprinting (finish), ACC-10 Hardware Placement | 18 SP

## Detailed User Stories

### ACC-01: Advanced CSI Feature Extraction Pipeline

Priority | Critical | Status | Not Started
Effort | 13 SP (2 sprints) | Sprint | Sprint 1-2

As a system, I want to extract rich, multi-dimensional features from raw CSI frames beyond simple amplitude variance, so that the detection engine has a comprehensive signal representation for high-accuracy classification

#### Description

Replace the current single-metric (blended variance) approach with a full feature extraction pipeline. Extract amplitude, phase, Doppler shift, and temporal features per subcarrier. This forms the foundation for all downstream ML models and dramatically improves signal-to-noise separation.

#### Acceptance Criteria

1. GIVEN raw CSI frames, WHEN processed through the pipeline, THEN at least 12 distinct features are extracted per subcarrier group
2. GIVEN a 60-second window, WHEN feature extraction runs, THEN amplitude variance, phase difference, Doppler FFT, autocorrelation lag-1, kurtosis, skewness, spectral entropy, and subcarrier correlation matrix are all computed
3. GIVEN noisy frames (SNR < 10dB), WHEN features are extracted, THEN outlier rejection discards frames with > 3 sigma deviation before feature computation
4. GIVEN the pipeline running on MeLE N100, WHEN processing 20 frames/sec from 2 nodes, THEN CPU usage stays below 40%
5. GIVEN extracted features, WHEN stored, THEN each feature vector includes node ID, timestamp (ms precision), and frame sequence number

#### Technical Tasks

1. Implement subcarrier grouping — Group 52 subcarriers into 8 logical bands (guard, pilot, data) to reduce dimensionality while preserving spatial information. Use OFDM subcarrier index mapping for 20MHz channels.
2. Add phase difference extraction — Compute phase difference between consecutive frames per subcarrier. Apply linear phase unwrapping to handle 2pi wraps. This captures motion-induced Doppler shifts.
3. Implement short-time FFT (Doppler) — 512-sample sliding window FFT on amplitude time-series per subcarrier band. Extract dominant frequency, spectral centroid, and bandwidth. Breathing: 0.2-0.5Hz, walking: 1-3Hz.
4. Add statistical features — Per window: mean, variance, kurtosis, skewness, IQR, entropy of amplitude distribution. These discriminate between empty room (Gaussian) vs. occupied (heavy-tailed).
5. Implement subcarrier correlation matrix — Compute Pearson correlation between subcarrier band amplitudes. Human presence breaks the correlation structure — use eigenvalue spread as a feature.
6. Build feature vector serializer — Output feature vectors as structured JSON with metadata. Support both real-time streaming (SSE) and batch export (CSV/Parquet) for ML training.
7. Add frame quality scoring — Score each frame based on: packet loss rate, RSSI stability, timestamp jitter. Reject frames below quality threshold. Log rejection rate for monitoring.

#### Dependencies

- ADR-018 binary frame protocol (implemented)
- ESP32-S3 firmware CSI collection (implemented)
- Node.js CSI bridge v3 (implemented)

#### Definition of Done

- Feature extraction pipeline integrated into csi-bridge.js
- Unit tests for each feature extractor with synthetic CSI data
- Performance benchmark on MeLE N100 meets <40% CPU target
- Feature vector API endpoint documented and tested
- 10-minute recording with features exported to CSV for validation

### ACC-02: ML-based Person Count Classifier

Priority | Critical | Status | Not Started
Effort | 21 SP (3 sprints) | Sprint | Sprint 2-4

As a system, I want to classify person count (0, 1, 2, 3+) using a trained ML model instead of threshold-based heuristics, so that detection accuracy exceeds 95% across diverse environments and conditions

#### Description

Train and deploy a lightweight ML model (Random Forest or small neural network) that takes the feature vectors from ACC-01 and classifies person count. The model must run in real-time on the MeLE N100 and support online learning for environment adaptation. This is the single highest-impact improvement for detection accuracy.

#### Acceptance Criteria

1. GIVEN labeled training data (min 2000 samples per class), WHEN the model is trained, THEN cross-validation accuracy exceeds 95% for 0-vs-1+ and 90% for exact count (0,1,2,3+)
2. GIVEN a trained model, WHEN deployed to MeLE N100, THEN inference latency is < 10ms per prediction
3. GIVEN a new environment, WHEN 30 minutes of labeled calibration data is collected, THEN the model achieves > 90% accuracy via transfer learning / fine-tuning
4. GIVEN the model running for 24 hours, WHEN environmental conditions drift (temperature, humidity, furniture movement), THEN accuracy degradation is < 5% from initial calibration
5. GIVEN a false positive (detecting person when empty), WHEN this occurs, THEN the system self-corrects within 30 seconds using temporal smoothing
6. GIVEN a model prediction, WHEN output, THEN it includes a confidence score (0-1) and the system flags low-confidence predictions (< 0.7) for human review

#### Technical Tasks

1. Design data collection protocol — Define labeling schema: {timestamp, node_id, true_count, activity_type}. Activity types: empty, stationary_sitting, stationary_standing, walking, multiple_people. Create collection UI with label buttons.
2. Build training data pipeline — Stream features from ACC-01 to labeled dataset. Support ground-truth labeling via button box, video timestamp sync, or manual annotation tool. Store in SQLite for portability.
3. Implement Random Forest classifier — Use ONNX Runtime for Node.js. Train RF with 200 trees, max_depth=12, min_samples_leaf=5. Feature importance analysis to identify top-10 discriminative features.
4. Implement lightweight neural network — 3-layer MLP (128-64-32-4 with ReLU). Train with PyTorch, export to ONNX. Compare with RF. Use dropout (0.3) and batch norm for regularization.
5. Build online learning module — Implement incremental learning: when confidence is high (>0.95) and consistent for 60s, add to training buffer. Retrain nightly or on manual trigger. Track model version history.
6. Implement model evaluation framework — Confusion matrix, per-class precision/recall/F1, ROC curves. Automated test against held-out validation set. Alert if production accuracy drops below threshold.
7. Build A/B comparison mode — Run old threshold-based and new ML-based detectors in parallel. Log both predictions. Dashboard comparing accuracy in real-time for validation.

#### Dependencies

- ACC-01: Feature Extraction Pipeline (required for input features)
- Labeled training dataset (min 4 hours across empty/1/2/3+ person scenarios)
- ONNX Runtime installed on MeLE N100

#### Definition of Done

- Model trained and validated with > 95% binary accuracy
- Deployed to MeLE N100 with < 10ms inference
- A/B comparison shows measurable improvement over threshold-based approach
- Online learning pipeline tested with simulated drift
- Model serialization and versioning documented

### ACC-03: Environment-Adaptive Baseline Calibration

Priority | Critical | Status | Partial
Effort | 8 SP (1 sprint) | Sprint | Sprint 1

As a system, I want to continuously adapt the empty-room baseline to environmental changes without manual recalibration, so that detection accuracy is maintained over days/weeks without operator intervention

#### Description

Enhance the existing rolling recalibration (v3) with multi-timescale adaptation, environment change detection, and automatic recovery from major disruptions (furniture moves, new equipment). The current CFAR-inspired approach is a good start but needs robustness improvements for production deployment.

#### Acceptance Criteria

1. GIVEN a stable empty room, WHEN baseline is tracked over 24 hours, THEN baseline drift is < 2% of initial values
2. GIVEN a furniture rearrangement, WHEN the environment changes significantly, THEN the system detects the change within 5 minutes and triggers a full recalibration within 15 minutes
3. GIVEN a multi-day deployment, WHEN diurnal temperature cycles occur, THEN the baseline tracks the slow drift without false-triggering recalibration
4. GIVEN an empty room period detected (e.g., nighttime), WHEN automatic recalibration triggers, THEN it completes silently and logs the event
5. GIVEN a manual recalibrate command via API, WHEN issued, THEN recalibration completes within 60 seconds with status feedback

#### Technical Tasks

1. Implement multi-timescale baseline tracking — Three EMA tracks: fast (alpha=0.1, 30s), medium (alpha=0.01, 5min), slow (alpha=0.001, 1hr). Use slow track for baseline, medium for drift detection, fast for transient rejection.
2. Add environment change detection (CUSUM) — Cumulative sum (CUSUM) algorithm on per-subcarrier baseline residuals. When cumulative deviation exceeds threshold, flag as environment change. Different thresholds for slow drift vs sudden change.
3. Build automatic empty-room detection — Heuristic: if variance stays below 1.2x baseline for > 10 minutes continuously, classify as empty. Use this window for opportunistic recalibration. Log confidence level.
4. Implement baseline persistence — Save baseline to disk every hour and on shutdown. Load on restart. Include metadata: timestamp, frame count, environment hash. Fall back to fresh calibration if file is > 24h old.
5. Add recalibration event logging — Structured log: {timestamp, trigger (scheduled/manual/change_detected), old_baseline_hash, new_baseline_hash, shift_magnitude, duration_ms}. Expose via /api/calibration/history.

#### Dependencies

- Rolling recalibration v3 (implemented in csi-bridge.js)
- Node health monitoring (implemented)

#### Definition of Done

- Multi-timescale tracking running in production
- CUSUM change detection tested with simulated environment changes
- Baseline persistence verified across server restarts
- 24-hour stability test passes with < 2% drift
- Calibration history API endpoint documented

### ACC-04: Multi-Node Spatial Fusion Engine

Priority | High | Status | Partial
Effort | 13 SP (2 sprints) | Sprint | Sprint 3-4

As a system, I want to fuse CSI data from multiple ESP32 nodes to determine not just presence but spatial location within a room, so that the system can distinguish between zones, track movement direction, and reduce false positives through spatial consistency

#### Description

The current multi-node fusion uses simple weighted averaging. This work package upgrades it to a probabilistic spatial model that combines observations from all nodes to estimate the most likely person location(s) within the coverage area. This enables room-level and eventually sub-room-level positioning.

#### Acceptance Criteria

1. GIVEN 3+ ESP32 nodes in a room, WHEN a person is present, THEN the system estimates position with < 2m accuracy (room-level zones)
2. GIVEN a person walking between two nodes, WHEN movement occurs, THEN the system detects transition direction within 3 seconds
3. GIVEN two people in different zones, WHEN both are stationary, THEN the system correctly identifies 2 occupied zones with > 85% accuracy
4. GIVEN a node failure, WHEN one ESP32 goes offline, THEN the system gracefully degrades using remaining nodes without false count changes
5. GIVEN node observations with different noise levels, WHEN fused, THEN noisy nodes contribute less to the estimate (automatic noise-weighted fusion)

#### Technical Tasks

1. Implement node topology model — Define node positions in room coordinates (x,y). Config file: {node_id, mac, x, y, orientation, antenna_pattern}. UI for placement on floor plan.
2. Build probabilistic occupancy grid — Discretize room into 1m x 1m cells. For each cell, compute P(occupied | CSI observations). Use node-to-cell distance and CSI amplitude attenuation model. Update at 5Hz.
3. Implement Bayesian sensor fusion — Each node produces a likelihood P(CSI | person_at_cell). Combine via Bayes rule across nodes. Use temporal prior (person unlikely to teleport) with motion model.
4. Add movement transition detection — Track occupancy grid changes over time. Detect zone entry/exit events. Implement hysteresis (must be in new zone for > 5s before triggering transition event).
5. Build graceful degradation handler — Monitor node heartbeats. On node loss: remove from fusion, widen uncertainty, increase remaining nodes' weights. On recovery: gradually reintroduce with lower initial weight.
6. Implement spatial consistency check — Cross-validate: if Node A sees 2 people but Nodes B and C see 0, flag inconsistency. Use voting + confidence to resolve. Log disagreements for debugging.

#### Dependencies

- ACC-01: Feature Extraction Pipeline (for per-node feature vectors)
- ACC-03: Adaptive Baseline (for reliable per-node occupancy estimates)
- Node topology configuration (new)
- Minimum 3 ESP32 nodes deployed in room

#### Definition of Done

- Occupancy grid visualization on dev heatmap
- Zone transition events emitted via SSE
- Degradation tested with simulated node failure
- Position accuracy validated against ground truth in test room
- Configuration UI for node placement
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

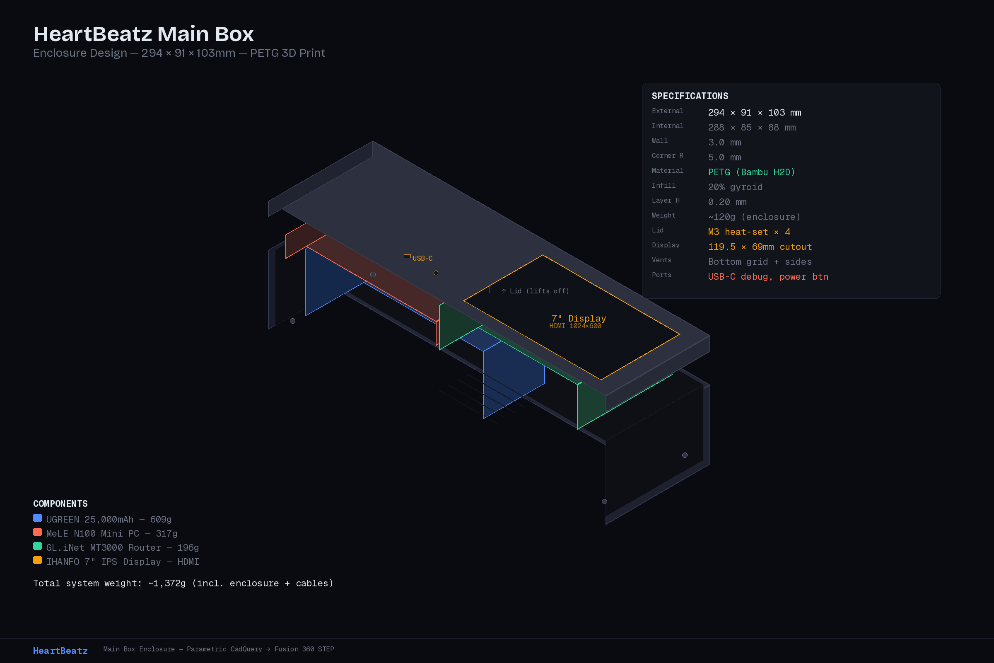
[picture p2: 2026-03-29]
cadquery/main_box_design.png

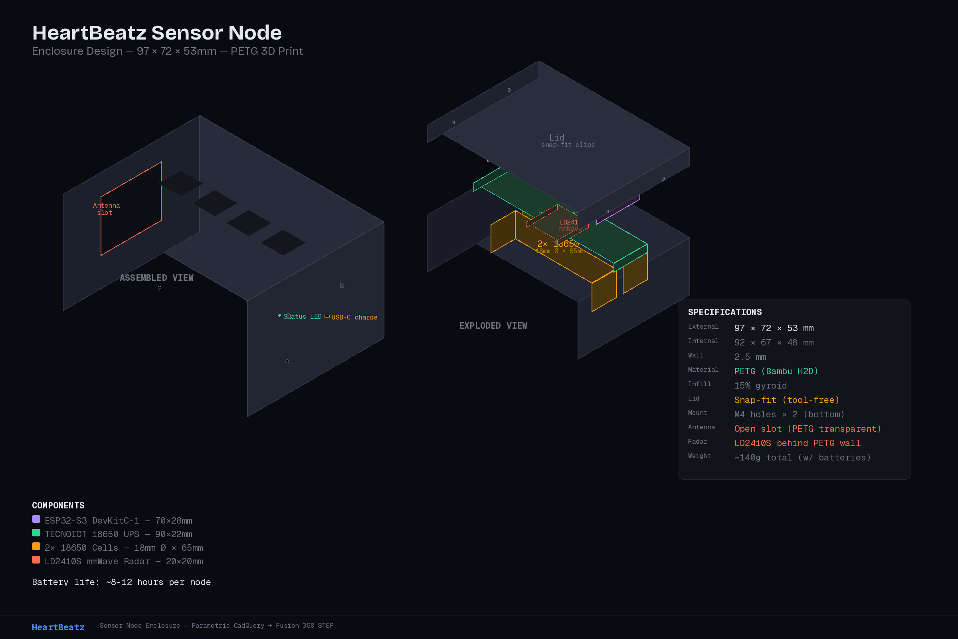
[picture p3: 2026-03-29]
cadquery/sensor_node_design.png

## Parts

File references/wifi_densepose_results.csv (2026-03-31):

Category | Metric | Value | Unit | Description
Hardware | WiFi_Transmitters | 3 | count | Number of WiFi transmitter antennas
Hardware | WiFi_Receivers | 3 | count | Number of WiFi receiver antennas
Hardware | Frequency_Range | 2.4GHz ± 20MHz | frequency | Operating frequency range
Hardware | Subcarriers | 30 | count | Number of subcarrier frequencies
Hardware | Sampling_Rate | 100 | Hz | CSI data sampling rate
Hardware | Total_Cost | 30 | USD | Hardware cost using TP-Link AC1750 routers
Architecture | Input_Amplitude_Shape | 150x3x3 | tensor | CSI amplitude input dimensions
Architecture | Input_Phase_Shape | 150x3x3 | tensor | CSI phase input dimensions
Architecture | Output_Feature_Shape | 3x720x1280 | tensor | Spatial feature map dimensions
Architecture | Body_Parts | 24 | count | Number of body parts detected
Architecture | Keypoints | 17 | count | Number of keypoints tracked (COCO format)
Training | Learning_Rate | 0.001 | rate | Initial learning rate
Training | Batch_Size | 16 | count | Training batch size
Training | Total_Iterations | 145000 | count | Total training iterations
Training | Lambda_DensePose | 0.6 | weight | DensePose loss weight
Training | Lambda_Keypoint | 0.3 | weight | Keypoint loss weight
Training | Lambda_Transfer | 0.1 | weight | Transfer learning loss weight
Performance | WiFi_Same_Layout_AP | 43.5 | AP | AP for WiFi_Same_Layout
Performance | WiFi_Same_Layout_AP@50 | 87.2 | AP | AP@50 for WiFi_Same_Layout
Performance | WiFi_Same_Layout_AP@75 | 44.6 | AP | AP@75 for WiFi_Same_Layout
Performance | WiFi_Same_Layout_AP-m | 38.1 | AP | AP-m for WiFi_Same_Layout
Performance | WiFi_Same_Layout_AP-l | 46.4 | AP | AP-l for WiFi_Same_Layout
Performance | WiFi_Same_Layout_dpAP_GPS | 45.3 | AP | dpAP_GPS for WiFi_Same_Layout
Performance | WiFi_Same_Layout_dpAP_GPS@50 | 79.3 | AP | dpAP_GPS@50 for WiFi_Same_Layout
Performance | WiFi_Same_Layout_dpAP_GPS@75 | 47.7 | AP | dpAP_GPS@75 for WiFi_Same_Layout
Performance | WiFi_Same_Layout_dpAP_GPSm | 43.2 | AP | dpAP_GPSm for WiFi_Same_Layout
Performance | WiFi_Same_Layout_dpAP_GPSm@50 | 77.4 | AP | dpAP_GPSm@50 for WiFi_Same_Layout
Performance | WiFi_Same_Layout_dpAP_GPSm@75 | 45.5 | AP | dpAP_GPSm@75 for WiFi_Same_Layout
Performance | Image_Same_Layout_AP | 84.7 | AP | AP for Image_Same_Layout
Performance | Image_Same_Layout_AP@50 | 94.4 | AP | AP@50 for Image_Same_Layout
Performance | Image_Same_Layout_AP@75 | 77.1 | AP | AP@75 for Image_Same_Layout
Performance | Image_Same_Layout_AP-m | 70.3 | AP | AP-m for Image_Same_Layout
Performance | Image_Same_Layout_AP-l | 83.8 | AP | AP-l for Image_Same_Layout
Performance | Image_Same_Layout_dpAP_GPS | 81.8 | AP | dpAP_GPS for Image_Same_Layout
Performance | Image_Same_Layout_dpAP_GPS@50 | 93.7 | AP | dpAP_GPS@50 for Image_Same_Layout
Performance | Image_Same_Layout_dpAP_GPS@75 | 86.2 | AP | dpAP_GPS@75 for Image_Same_Layout
Performance | Image_Same_Layout_dpAP_GPSm | 84.0 | AP | dpAP_GPSm for Image_Same_Layout
Performance | Image_Same_Layout_dpAP_GPSm@50 | 94.9 | AP | dpAP_GPSm@50 for Image_Same_Layout
Performance | Image_Same_Layout_dpAP_GPSm@75 | 86.8 | AP | dpAP_GPSm@75 for Image_Same_Layout
Performance | WiFi_Different_Layout_AP | 27.3 | AP | AP for WiFi_Different_Layout
Performance | WiFi_Different_Layout_AP@50 | 51.8 | AP | AP@50 for WiFi_Different_Layout
Performance | WiFi_Different_Layout_AP@75 | 24.2 | AP | AP@75 for WiFi_Different_Layout
Performance | WiFi_Different_Layout_AP-m | 22.1 | AP | AP-m for WiFi_Different_Layout
Performance | WiFi_Different_Layout_AP-l | 28.6 | AP | AP-l for WiFi_Different_Layout
Performance | WiFi_Different_Layout_dpAP_GPS | 25.4 | AP | dpAP_GPS for WiFi_Different_Layout
Performance | WiFi_Different_Layout_dpAP_GPS@50 | 50.2 | AP | dpAP_GPS@50 for WiFi_Different_Layout
Performance | WiFi_Different_Layout_dpAP_GPS@75 | 24.7 | AP | dpAP_GPS@75 for WiFi_Different_Layout
Performance | WiFi_Different_Layout_dpAP_GPSm | 23.2 | AP | dpAP_GPSm for WiFi_Different_Layout
Performance | WiFi_Different_Layout_dpAP_GPSm@50 | 47.4 | AP | dpAP_GPSm@50 for WiFi_Different_Layout
Performance | WiFi_Different_Layout_dpAP_GPSm@75 | 26.5 | AP | dpAP_GPSm@75 for WiFi_Different_Layout
Ablation | Amplitude_Only_AP | 39.5 | AP | Performance with amplitude only
Ablation | Plus_Phase_AP | 40.3 | AP | Performance adding phase information
Ablation | Plus_Keypoints_AP | 42.9 | AP | Performance adding keypoint supervision
Ablation | Final_Model_AP | 43.5 | AP | Performance with transfer learning
Advantages | Through_Walls | Yes | boolean | Can detect through walls and obstacles
Advantages | Privacy_Preserving | Yes | boolean | No visual recording required
Advantages | Lighting_Independent | Yes | boolean | Works in complete darkness
Advantages | Low_Cost | Yes | boolean | Uses standard WiFi equipment
Advantages | Real_Time | Yes | boolean | Multiple frames per second
Advantages | Multiple_People | Yes | boolean | Can track multiple people simultaneously

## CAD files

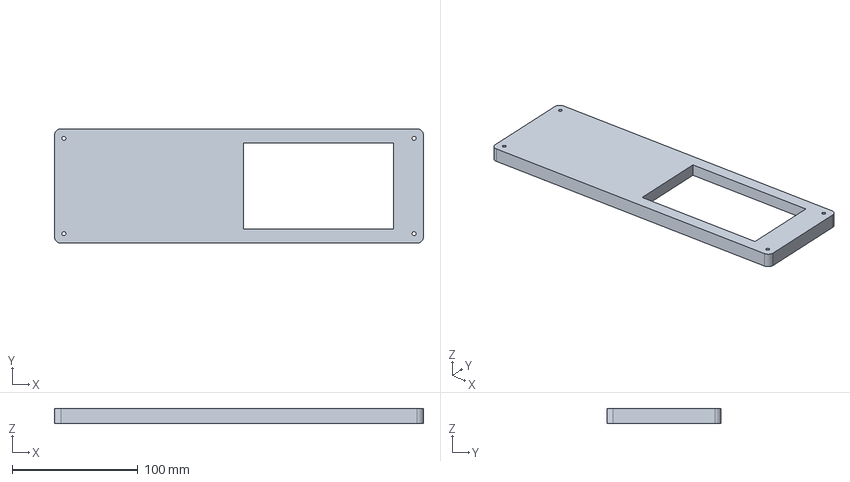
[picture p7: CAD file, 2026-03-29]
cadquery/main_box_lid.step
294.0 x 91.0 x 12.0 mm

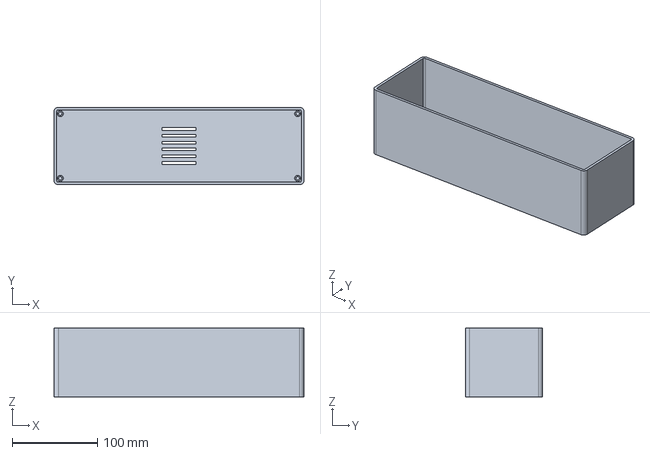
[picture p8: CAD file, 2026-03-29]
cadquery/main_box_base.step
294.0 x 91.0 x 81.0 mm

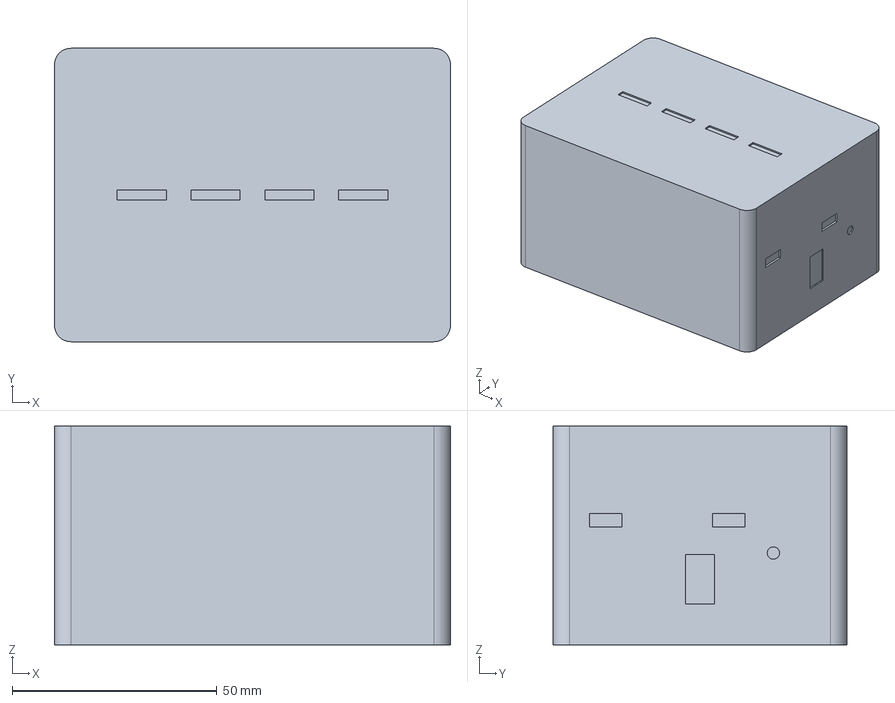
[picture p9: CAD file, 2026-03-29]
cadquery/sensor_node_assembly.step
96.6 x 71.6 x 53.4 mm

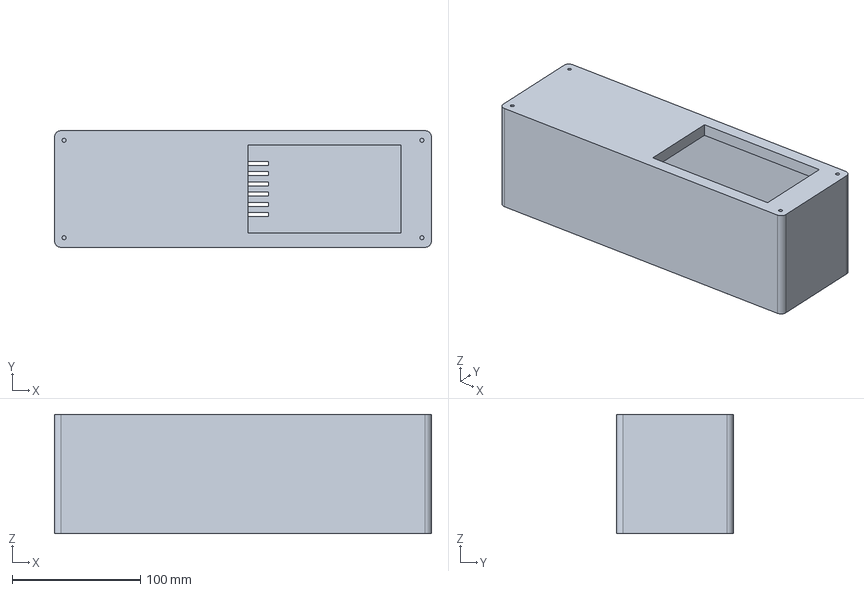
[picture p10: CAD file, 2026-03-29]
cadquery/main_box_assembly.step
294.0 x 91.0 x 93.0 mm

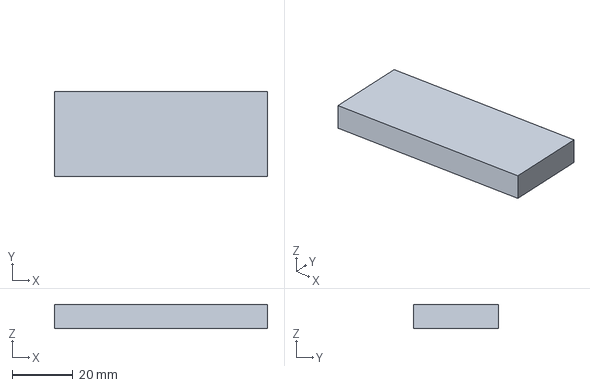
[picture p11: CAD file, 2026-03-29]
cadquery/ref_esp32_s3.step
70.0 x 28.0 x 8.00 mm

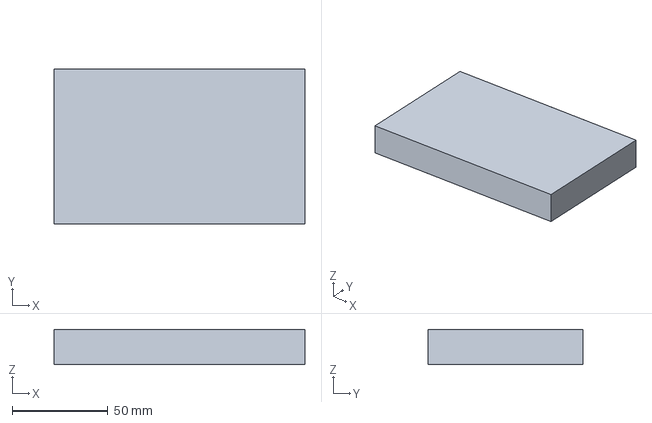
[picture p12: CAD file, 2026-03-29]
cadquery/ref_mele_n100.step
131.0 x 81.0 x 18.3 mm

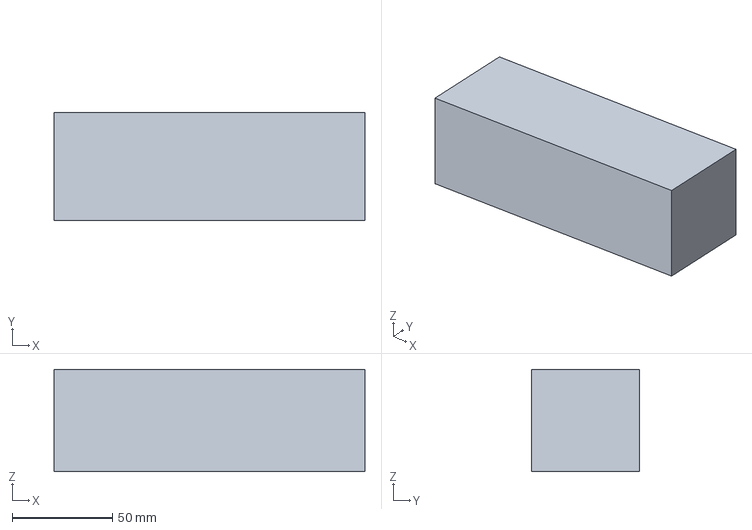
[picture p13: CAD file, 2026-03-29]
cadquery/ref_battery_ugreen.step
155.0 x 54.0 x 51.0 mm

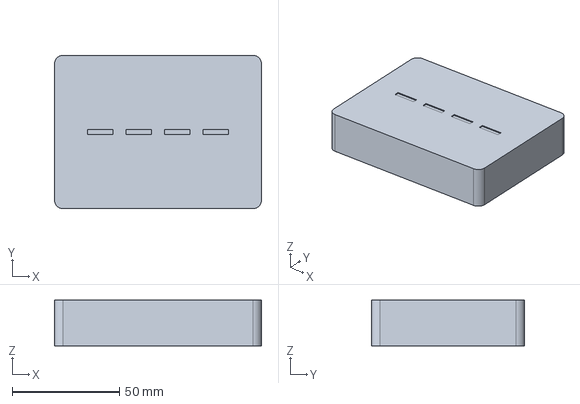
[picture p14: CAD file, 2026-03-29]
cadquery/sensor_node_lid.step
96.6 x 71.6 x 21.4 mm

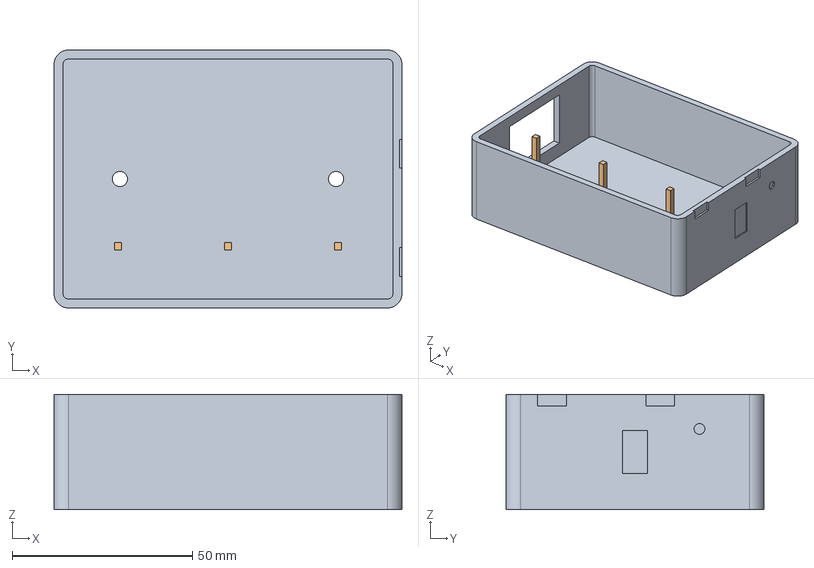
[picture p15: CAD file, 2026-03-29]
cadquery/sensor_node_base.step
96.6 x 71.6 x 32.0 mm

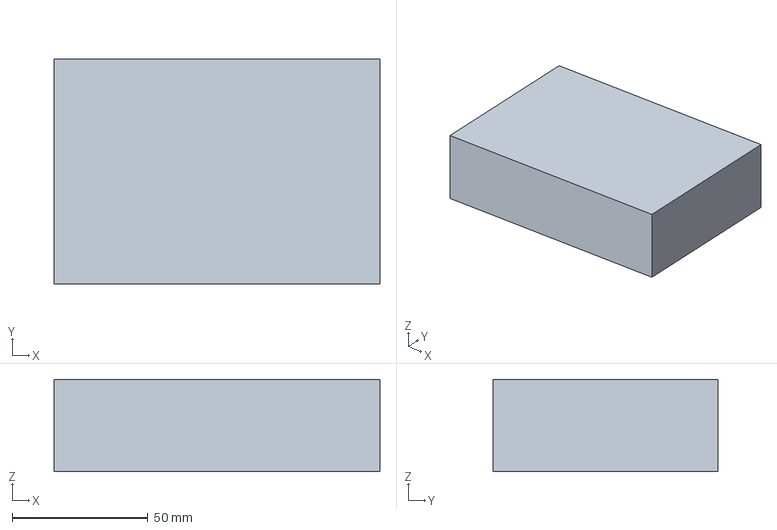
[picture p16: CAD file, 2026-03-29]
cadquery/ref_router_mt3000.step
120.0 x 83.0 x 34.0 mm

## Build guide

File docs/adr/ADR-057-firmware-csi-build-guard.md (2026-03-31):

# ADR-057: Firmware CSI Build Guard and sdkconfig.defaults

| Field | Value |
|---|---|
| **Status**  | Accepted |
| **Date** | 2026-03-12 |
| **Authors** | ruv |
| **Issues**  | #223, #238, #234, #210, #190 |

## Context

Multiple GitHub issues (#223, #238, #234, #210, #190) report firmware problems
that fall into two categories:

1. **CSI not enabled at runtime** — The committed `sdkconfig` had
   `# CONFIG_ESP_WIFI_CSI_ENABLED is not set` (line 1135), meaning users who
   built from source or used pre-built binaries got the runtime error:
   `E (6700) wifi:CSI not enabled in menuconfig!`

   Root cause: `sdkconfig.defaults.template` existed with the correct setting
   (`CONFIG_ESP_WIFI_CSI_ENABLED=y`) but ESP-IDF only reads
   `sdkconfig.defaults` — not `.template` suffixed files. No `sdkconfig.defaults`
   file was committed.

2. **Unsupported ESP32 variants** — Users attempting to use original ESP32
   (D0WD) and ESP32-C3 boards. The firmware targets ESP32-S3 only
   (`CONFIG_IDF_TARGET="esp32s3"`, Xtensa architecture) and this was not
   surfaced clearly enough in documentation or build errors.

## Decision

### Fix 1: Commit `sdkconfig.defaults` (not just template)

Copy `sdkconfig.defaults.template` → `sdkconfig.defaults` so that ESP-IDF
applies the correct defaults (including `CONFIG_ESP_WIFI_CSI_ENABLED=y`)
automatically when `sdkconfig` is regenerated.

### Fix 2: `#error` compile-time guard in `csi_collector.c`

Add a preprocessor guard:

```c
#ifndef CONFIG_ESP_WIFI_CSI_ENABLED
#error "CONFIG_ESP_WIFI_CSI_ENABLED must be set in sdkconfig."
#endif
```

This turns a confusing runtime crash into a clear compile-time error with
instructions on how to fix it.

### Fix 3: Fix committed `sdkconfig`

Change line 1135 from `# CONFIG_ESP_WIFI_CSI_ENABLED is not set` to
`CONFIG_ESP_WIFI_CSI_ENABLED=y`.

## Consequences

- **Positive**: New builds will always have CSI enabled. Users building from
  source will get a clear compile error if CSI is somehow disabled.
- **Positive**: Pre-built release binaries will include CSI support.
- **Neutral**: Original ESP32 and ESP32-C3 remain unsupported. This is by
  design — only ESP32-S3 has the CSI API surface we depend on. Future ADRs
  may address multi-target support if demand warrants it.
- **Negative**: None identified.

## Hardware Support Matrix

| Variant | CSI Support | Firmware Target | Status |
|---|---|---|---|
| ESP32-S3 | Yes | Yes | Supported |
| ESP32 (orig) | Partial | No | Unsupported |
| ESP32-C3 | Yes (IDF 5.1+) | No | Unsupported |
| ESP32-C6 | Yes | No | Unsupported |

## Notes

- ESP32-C3 and C6 use RISC-V architecture; a separate build target
  (`idf.py set-target esp32c3`) would be needed.
- Original ESP32 has limited CSI (no STBC HT-LTF2, fewer subcarriers).
- Users on unsupported hardware can still write custom firmware using the
  ADR-018 binary frame format (magic `0xC5110001`) for interop with the
  Rust aggregator.

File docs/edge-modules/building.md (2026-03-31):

# Smart Building Modules -- WiFi-DensePose Edge Intelligence

> Make any building smarter using WiFi signals you already have. Know which rooms are occupied, control HVAC and lighting automatically, count elevator passengers, track meeting room usage, and audit energy waste -- all without cameras or badges.

## Overview

| Module | File | What It Does | Event IDs | Frame Budget |
|---|---|---|---|---|
| HVAC Presence | `bld_hvac_presence.rs` | Presence detection tuned for HVAC energy management | 310-312 | ~0.5 us/frame |
| Lighting Zones | `bld_lighting_zones.rs` | Per-zone lighting control (On/Dim/Off) based on spatial occupancy | 320-322 | ~1 us/frame |
| Elevator Count | `bld_elevator_count.rs` | Occupant counting in elevator cabins (1-12 persons) | 330-333 | ~1.5 us/frame |
| Meeting Room | `bld_meeting_room.rs` | Meeting lifecycle tracking with utilization metrics | 340-343 | ~0.3 us/frame |
| Energy Audit | `bld_energy_audit.rs` | 24x7 hourly occupancy histograms for scheduling optimization | 350-352 | ~0.2 us/frame |

All modules target the ESP32-S3 running WASM3 (ADR-040 Tier 3). They receive pre-processed CSI signals from Tier 2 DSP and emit structured events via `csi_emit_event()`.

---

## Modules

### HVAC Presence Control (`bld_hvac_presence.rs`)

**What it does**: Tells your HVAC system whether a room is occupied, with intentionally asymmetric timing -- fast arrival detection (10 seconds) so cooling/heating starts quickly, and slow departure timeout (5 minutes) to avoid premature shutoff when someone briefly steps out. Also classifies whether the occupant is sedentary (desk work, reading) or active (walking, exercising).

**How it works**: A four-state machine processes presence scores and motion energy each frame:

```
Vacant --> ArrivalPending --> Occupied --> DeparturePending --> Vacant
           (10s debounce)                 (5 min timeout)
```

Motion energy is smoothed with an exponential moving average (alpha=0.1) and classified against a threshold of 0.3 to distinguish sedentary from active behavior.

#### State Machine

| State | Entry Condition | Exit Condition |
|---|---|---|
| `Vacant` | No presence detected | Presence score > 0.5 |
| `ArrivalPending` | Presence detected, debounce counting | 200 consecutive frames with presence -> Occupied; any absence -> Vacant |
| `Occupied` | Arrival debounce completed | First frame without presence -> DeparturePending |
| `DeparturePending` | Presence lost | 6000 frames without presence -> Vacant; any presence -> Occupied |

#### Events

| Event ID | Name | Value | When Emitted |
|---|---|---|---|
| 310 | `HVAC_OCCUPIED` | 1.0 (occupied) or 0.0 (vacant) | Every 20 frames |
| 311 | `ACTIVITY_LEVEL` | 0.0-0.99 (sedentary + EMA) or 1.0 (active) | Every 20 frames |
| 312 | `DEPARTURE_COUNTDOWN` | 0.0-1.0 (fraction of timeout remaining) | Every 20 frames during DeparturePending |

#### API

```rust
use wifi_densepose_wasm_edge::bld_hvac_presence::HvacPresenceDetector;

let mut det = HvacPresenceDetector::new();

// Per-frame processing
let events = det.process_frame(presence_score, motion_energy);
// events: &[(event_type: i32, value: f32)]

// Queries
det.state()       // -> HvacState (Vacant|ArrivalPending|Occupied|DeparturePending)
det.is_occupied()  // -> bool (true during Occupied or DeparturePending)
det.activity()     // -> ActivityLevel (Sedentary|Active)
det.motion_ema()   // -> f32 (smoothed motion energy)
```

#### Configuration Constants

| Constant | Value | Description |
|---|---|---|
| `ARRIVAL_DEBOUNCE` | 200 frames (10s) | Frames of continuous presence before confirming occupancy |
| `DEPARTURE_TIMEOUT` | 6000 frames (5 min) | Frames of continuous absence before declaring vacant |
| `ACTIVITY_THRESHOLD` | 0.3 | Motion EMA above this = Active |
| `MOTION_ALPHA` | 0.1 | EMA smoothing factor for motion energy |
| `PRESENCE_THRESHOLD` | 0.5 | Minimum presence score to consider someone present |
| `EMIT_INTERVAL` | 20 frames (1s) | Event emission interval |

#### Example: BACnet Integration

```python
# Python host reading events from ESP32 UDP packet
if event_id == 310:  # HVAC_OCCUPIED
    bacnet_write(device_id, "Occupancy", int(value))  # 1=occupied, 0=vacant
elif event_id == 311:  # ACTIVITY_LEVEL
    if value >= 1.0:
        bacnet_write(device_id, "CoolingSetpoint", 72)  # Active: cooler
    else:
        bacnet_write(device_id, "CoolingSetpoint", 76)  # Sedentary: warmer
elif event_id == 312:  # DEPARTURE_COUNTDOWN
    if value < 0.2:  # Less than 1 minute remaining
        bacnet_write(device_id, "FanMode", "low")  # Start reducing
```

---

### Lighting Zone Control (`bld_lighting_zones.rs`)

**What it does**: Manages up to 4 independent lighting zones, automatically transitioning each zone between On (occupied and active), Dim (occupied but sedentary for over 10 minutes), and Off (vacant for over 30 seconds). Uses per-zone variance analysis to determine which areas of the room have people.

**How it works**: Subcarriers are divided into groups (one per zone). Each group's amplitude variance is computed and compared against a calibrated baseline. Variance deviation above threshold indicates occupancy in that zone. A calibration phase (200 frames = 10 seconds) establishes the baseline with an empty room.

```
Off --> On (occupancy + activity detected)
On --> Dim (occupied but sedentary for 10 min)
On --> Dim (vacancy detected, grace period)
Dim --> Off (vacant for 30 seconds)
Dim --> On (activity resumes)
```

#### Events

| Event ID | Name | Value | When Emitted |
|---|---|---|---|
| 320 | `LIGHT_ON` | zone_id (0-3) | On state transition |
| 321 | `LIGHT_DIM` | zone_id (0-3) | Dim state transition |
| 322 | `LIGHT_OFF` | zone_id (0-3) | Off state transition |

Periodic summaries encode `zone_id + confidence` in the value field (integer part = zone, fractional part = occupancy score).

#### API

```rust
use wifi_densepose_wasm_edge::bld_lighting_zones::LightingZoneController;

let mut ctrl = LightingZoneController::new();

// Per-frame: pass subcarrier amplitudes and overall motion energy
let events = ctrl.process_frame(&amplitudes, motion_energy);

// Queries
ctrl.zone_state(zone_id) // -> LightState (Off|Dim|On)
ctrl.n_zones()           // -> usize (number of active zones, 1-4)
ctrl.is_calibrated()     // -> bool
```

#### Configuration Constants

| Constant | Value | Description |
|---|---|---|
| `MAX_ZONES` | 4 | Maximum lighting zones |
| `OCCUPANCY_THRESHOLD` | 0.03 | Variance deviation ratio for occupancy |
| `ACTIVE_THRESHOLD` | 0.25 | Motion energy for active classification |
| `DIM_TIMEOUT` | 12000 frames (10 min) | Sedentary frames before dimming |
| `OFF_TIMEOUT` | 600 frames (30s) | Vacant frames before turning off |
| `BASELINE_FRAMES` | 200 frames (10s) | Calibration duration |

#### Example: DALI/KNX Lighting

```python
# Map zone events to DALI addresses
DALI_ADDR = {0: 1, 1: 2, 2: 3, 3: 4}

if event_id == 320:  # LIGHT_ON
    zone = int(value)
    dali_send(DALI_ADDR[zone], level=254)  # Full brightness
elif event_id == 321:  # LIGHT_DIM
    zone = int(value)
    dali_send(DALI_ADDR[zone], level=80)   # 30% brightness
elif event_id == 322:  # LIGHT_OFF
    zone = int(value)
    dali_send(DALI_ADDR[zone], level=0)    # Off
```

---

### Elevator Occupancy Counting (`bld_elevator_count.rs`)

**What it does**: Counts the number of people in an elevator cabin (0-12), detects door open/close events, and emits overload warnings when the count exceeds a configurable threshold. Uses the confined-space multipath characteristics of an elevator to correlate amplitude variance with body count.

**How it works**: In a small reflective metal box like an elevator, each additional person adds significant multipath scattering. The module calibrates on the empty cabin, then maps the ratio of current variance to baseline variance onto a person count. Frame-to-frame amplitude deltas detect sudden geometry changes (door open/close). Count estimate fuses the module's own variance-based estimate (40% weight) with the host's person count hint (60% weight) when available.

#### Events

| Event ID | Name | Value | When Emitted |
|---|---|---|---|
| 330 | `ELEVATOR_COUNT` | Person count (0-12) | Every 10 frames |
| 331 | `DOOR_OPEN` | Current count at time of opening | On door open detection |
| 332 | `DOOR_CLOSE` | Current count at time of closing | On door close detection |
| 333 | `OVERLOAD_WARNING` | Current count | When count >= overload threshold |

#### API

```rust
use wifi_densepose_wasm_edge::bld_elevator_count::ElevatorCounter;

let mut ec = ElevatorCounter::new();

// Per-frame: amplitudes, phases, motion energy, host person count hint
let events = ec.process_frame(&amplitudes, &phases, motion_energy, host_n_persons);

// Queries
ec.occupant_count()    // -> u8 (0-12)
ec.door_state()        // -> DoorState (Open|Closed)
ec.is_calibrated()     // -> bool

// Configuration
ec.set_overload_threshold(8); // Set custom overload limit
```

#### Configuration Constants

| Constant | Value | Description |
|---|---|---|
| `MAX_OCCUPANTS` | 12 | Maximum tracked occupants |
| `DEFAULT_OVERLOAD` | 10 | Default overload warning threshold |
| `DOOR_VARIANCE_RATIO` | 4.0 | Delta magnitude for door detection |
| `DOOR_DEBOUNCE` | 3 frames | Debounce for door events |
| `DOOR_COOLDOWN` | 40 frames (2s) | Cooldown after door event |
| `BASELINE_FRAMES` | 200 frames (10s) | Calibration with empty cabin |

---

### Meeting Room Tracker (`bld_meeting_room.rs`)

**What it does**: Tracks the full lifecycle of meeting room usage -- from someone entering, to confirming a genuine multi-person meeting, to detecting when the meeting ends and the room is available again. Distinguishes actual meetings (2+ people for more than 3 seconds) from a single person briefly using the room. Tracks peak headcount and calculates room utilization rate.

**How it works**: A four-state machine processes presence and person count:

```
Empty --> PreMeeting --> Active --> PostMeeting --> Empty
          (someone        (2+ people       (everyone left,
           entered)        confirmed)       2 min cooldown)
```

The PreMeeting state has a 3-minute timeout: if only one person remains, the room is not promoted to "Active" (it is not counted as a meeting).

#### Events

| Event ID | Name | Value | When Emitted |
|---|---|---|---|
| 340 | `MEETING_START` | Current person count | On transition to Active |
| 341 | `MEETING_END` | Duration in minutes | On transition to PostMeeting |
| 342 | `PEAK_HEADCOUNT` | Peak person count | On meeting end + periodic during Active |
| 343 | `ROOM_AVAILABLE` | 1.0 | On transition from PostMeeting to Empty |

#### API

```rust
use wifi_densepose_wasm_edge::bld_meeting_room::MeetingRoomTracker;

let mut mt = MeetingRoomTracker::new();

// Per-frame: presence (0/1), person count, motion energy
let events = mt.process_frame(presence, n_persons, motion_energy);

// Queries
mt.state()            // -> MeetingState (Empty|PreMeeting|Active|PostMeeting)
mt.peak_headcount()   // -> u8
mt.meeting_count()    // -> u32 (total meetings since reset)
mt.utilization_rate() // -> f32 (fraction of time in meetings, 0.0-1.0)
```

#### Configuration Constants

| Constant | Value | Description |
|---|---|---|
| `MEETING_MIN_PERSONS` | 2 | Minimum people for a "meeting" |
| `PRE_MEETING_TIMEOUT` | 3600 frames (3 min) | Max time waiting for meeting to form |
| `POST_MEETING_TIMEOUT` | 2400 frames (2 min) | Cooldown before marking room available |
| `MEETING_MIN_FRAMES` | 6000 frames (5 min) | Reference minimum meeting duration |

#### Example: Calendar Integration

```python
# Sync meeting room status with calendar system
if event_id == 340:  # MEETING_START
    calendar_api.mark_room_in_use(room_id, headcount=int(value))
elif event_id == 341:  # MEETING_END
    duration_min = value
    calendar_api.log_actual_usage(room_id, duration_min)
elif event_id == 343:  # ROOM_AVAILABLE
    calendar_api.mark_room_available(room_id)
    display_screen.show("Room Available")
```

---

### Energy Audit (`bld_energy_audit.rs`)

**What it does**: Builds a 7-day, 24-hour occupancy histogram (168 hourly bins) to identify energy waste patterns. Finds which hours are consistently unoccupied (candidates for HVAC/lighting shutoff), detects after-hours occupancy anomalies (security/safety concern), and reports overall building utilization.

**How it works**: Each frame increments the appropriate hour bin's counters. The module maintains its own simulated clock (hour/day) that advances by counting frames (72,000 frames = 1 hour at 20 Hz). The host can set the real time via `set_time()`. After-hours is defined as 22:00-06:00 (wraps midnight correctly). Sustained presence (30+ seconds) during after-hours triggers an alert.

#### Events

| Event ID | Name | Value | When Emitted |
|---|---|---|---|
| 350 | `SCHEDULE_SUMMARY` | Current hour's occupancy rate (0.0-1.0) | Every 1200 frames (1 min) |
| 351 | `AFTER_HOURS_ALERT` | Current hour (22-5) | After 600 frames (30s) of after-hours presence |
| 352 | `UTILIZATION_RATE` | Overall utilization (0.0-1.0) | Every 1200 frames (1 min) |

#### API

```rust
use wifi_densepose_wasm_edge::bld_energy_audit::EnergyAuditor;

let mut ea = EnergyAuditor::new();

// Set real time from host
ea.set_time(0, 8); // Monday 8 AM (day 0-6, hour 0-23)

// Per-frame: presence (0/1), person count
let events = ea.process_frame(presence, n_persons);

// Queries
ea.utilization_rate()          // -> f32 (overall)
ea.hourly_rate(day, hour)      // -> f32 (occupancy rate for specific slot)
ea.hourly_headcount(day, hour) // -> f32 (average headcount)
ea.unoccupied_hours(day)       // -> u8 (hours below 10% occupancy)
ea.current_time()              // -> (day, hour)
```

#### Configuration Constants

| Constant | Value | Description |
|---|---|---|
| `FRAMES_PER_HOUR` | 72000 | Frames in one hour at 20 Hz |
| `SUMMARY_INTERVAL` | 1200 frames (1 min) | How often to emit summaries |
| `AFTER_HOURS_START` | 22 (10 PM) | Start of after-hours window |
| `AFTER_HOURS_END` | 6 (6 AM) | End of after-hours window |
| `USED_THRESHOLD` | 0.1 | Minimum occupancy rate to consider an hour "used" |
| `AFTER_HOURS_ALERT_FRAMES` | 600 frames (30s) | Sustained presence before alert |

#### Example: Energy Optimization Report

```python
# Generate weekly energy optimization report
for day in range(7):
    unused = auditor.unoccupied_hours(day)
    print(f"{DAY_NAMES[day]}: {unused} hours could have HVAC off")

    for hour in range(24):
        rate = auditor.hourly_rate(day, hour)
        if rate < 0.1:
            print(f"  {hour:02d}:00 - unused ({rate:.0%} occupancy)")
```

---

## Integration Guide

### Connecting to BACnet / HVAC Systems

All five building modules emit events via the standard `csi_emit_event()` interface. A typical integration path:

1. **ESP32 firmware** receives events from the WASM module
2. **UDP packet** carries events to the aggregator server (port 5005)
3. **Sensing server** (`wifi-densepose-sensing-server`) exposes events via REST API
4. **BMS integration script** polls the API and writes BACnet/Modbus objects

Key BACnet object mappings:

| Module | BACnet Object Type | Property |
|---|---|---|
| HVAC Presence | Binary Value | Occupancy (310: 1=occupied) |
| HVAC Presence | Analog Value | Activity Level (311: 0-1) |
| Lighting Zones | Multi-State Value | Zone State (320-322: Off/Dim/On) |
| Elevator Count | Analog Value | Occupant Count (330: 0-12) |
| Meeting Room | Binary Value | Room In Use (340/343) |
| Energy Audit | Analog Value | Utilization Rate (352: 0-1.0) |

### Lighting Control Integration (DALI, KNX)

The `bld_lighting_zones` module emits zone-level On/Dim/Off transitions. Map each zone to a DALI address group or KNX group address:

- Event 320 (LIGHT_ON) -> DALI command `DAPC(254)` or KNX `DPT_Switch ON`
- Event 321 (LIGHT_DIM) -> DALI command `DAPC(80)` or KNX `DPT_Scaling 30%`
- Event 322 (LIGHT_OFF) -> DALI command `DAPC(0)` or KNX `DPT_Switch OFF`

### BMS (Building Management System) Integration

For full BMS integration combining all five modules:

```
ESP32 Nodes (per room/zone)
    |
    v  UDP events
Aggregator Server
    |
    v  REST API / WebSocket
BMS Gateway Script
    |
    +-- HVAC Controller (BACnet/Modbus)
    +-- Lighting Controller (DALI/KNX)
    +-- Elevator Display Panel
    +-- Meeting Room Booking System
    +-- Energy Dashboard
```

### Deployment Considerations

- **Calibration**: Lighting and Elevator modules require a 10-second calibration with an empty room/cabin. Schedule calibration during known unoccupied periods.
- **Clock sync**: The Energy Audit module needs `set_time()` called at startup. Use NTP on the aggregator or pass timestamp via the host API.
- **Multiple ESP32s**: For open-plan offices, deploy one ESP32 per zone. Each runs its own HVAC Presence and Lighting Zones instance. The aggregator merges zone-level data.
- **Event rate**: All modules throttle events to at most one emission per second (EMIT_INTERVAL = 20 frames). Total bandwidth per module is under 100 bytes/second.

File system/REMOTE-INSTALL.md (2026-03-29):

# HeartBeatz — Fully Remote Install (No Keyboard)

## Overview

This guide gets Ubuntu + HeartBeatz running on the MeLE N100 without ever
touching a keyboard. You only need your laptop and a USB stick.

**Total time: ~20 minutes hands-on, ~15 minutes waiting**

---

## What You Need

- MeLE N100 (just arrived)
- USB stick (8GB+)
- Ethernet cable (MeLE → GL.iNet router, or your home network for now)
- HDMI cable + IHANFO 7" display (optional — just to see what's happening)
- Your laptop (Windows) to prepare the USB stick

---

## The One Catch: BIOS Boot Order

There IS one moment where you might need a keyboard: telling the MeLE to
boot from USB instead of its internal Windows drive.

**Try this first (often works on MeLE):**

Many MeLE N100 models auto-detect a bootable USB and boot from it.
Just plug in the USB, power on, and wait 30 seconds. If you see the
Ubuntu installer starting, you're golden — skip to "Wait for Install".

**If it boots to Windows instead:**

You have 3 options (easiest first):

### Option A: Change boot order from Windows (fully remote)
1. Connect MeLE to your network via Ethernet
2. Let it boot to Windows
3. Find its IP in your router admin page (http://192.168.8.1 → DHCP leases)
4. Remote Desktop into it from your laptop:
   - Windows: `mstsc` → enter the IP
   - Mac: install "Microsoft Remote Desktop" from App Store
   - Note: Windows RDP might not be enabled by default. If this doesn't work, try Option B
5. Once in Windows, open CMD as admin and run:
   ```
   bcdedit /set {fwbootmgr} displayorder {bootmgr} /addfirst
   shutdown /r /fw /t 0
   ```
   This reboots into BIOS settings. From there you can change boot order.

### Option B: Use Windows to flash Ubuntu (fully remote)
If you can RDP into Windows but can't change BIOS:
1. Remote Desktop into the MeLE
2. Download Rufus + Ubuntu ISO inside Windows
3. Run Rufus, flash the USB **while Windows is running**
4. Open CMD as admin: `shutdown /r /o /t 0`
5. This opens "Advanced Startup" → "Use a device" → select USB

### Option C: Borrow a keyboard for 10 seconds
Plug in any USB keyboard, press **F7** at boot to get the boot menu,
select the USB stick, unplug the keyboard. Done. Everything after this
is remote.

---

## Step 1: Prepare the Autoinstall USB (~5 min)

On your laptop:

### 1a. Download Ubuntu Server 22.04.4 LTS
https://ubuntu.com/download/server

### 1b. Flash it with Rufus
1. Download [Rufus](https://rufus.ie/) (portable version is fine)
2. Insert USB stick
3. In Rufus:
   - Device: your USB stick
   - Boot selection: the Ubuntu ISO
   - Partition scheme: GPT
   - Click START
   - If asked about ISO mode: choose "Write in ISO Image mode"
4. Wait for it to finish

### 1c. Add the autoinstall config
After Rufus finishes, the USB stick should appear as a drive in Explorer.

1. Open the USB stick in Explorer
2. Create a folder called `autoinstall` in the root of the USB
3. Copy these two files from `HeartBeatz/system/autoinstall/` into that folder:
   - `user-data`
   - `meta-data`

Your USB should now have:
```
USB drive (E:)
├── autoinstall/
│   ├── user-data
│   └── meta-data
├── boot/
├── casper/
├── ... (other Ubuntu files)
```

### 1d. Make it truly unattended (skip the confirmation prompt)

Edit the file `boot/grub/grub.cfg` on the USB stick.

Find the line that says:
```
linux /casper/vmlinuz ---
```

Change it to:
```
linux /casper/vmlinuz autoinstall ds=nocloud;s=/cdrom/autoinstall/ ---
```

This tells Ubuntu: "Yes, really install automatically, and here's my config."

---

## Step 2: Boot the MeLE from USB

1. Plug the USB stick into the MeLE
2. Connect Ethernet cable
3. (Optional) Connect HDMI to 7" display so you can watch
4. Power on

If the BIOS is set to try USB first (or you changed it), Ubuntu starts
installing automatically. You'll see text scrolling on the display.

**The install takes about 10-15 minutes.** It will:
- Wipe the internal drive (bye Windows)
- Install Ubuntu Server 22.04
- Create user `heartbeatz` with password `heartbeatz`
- Enable SSH
- Reboot automatically when done

---

## Step 3: SSH In (~2 min after reboot)

After the MeLE reboots from its internal drive:

1. Wait 2-3 minutes for it to fully boot
2. Find its IP:
   - Check your router admin page (http://192.168.8.1), OR
   - Try: `ping heartbeatz.local` from your laptop, OR
   - Try common DHCP addresses: `ssh heartbeatz@192.168.8.x`
3. SSH in:
   ```
   ssh heartbeatz@<IP_ADDRESS>
   ```
   Password: `heartbeatz`

The first-boot service will have already installed Docker, Node.js, and
Chromium. Check with:
```bash
docker --version
node --version
```

If they're not installed yet, wait a few minutes — the first-boot script
runs after network is available. Check its progress:
```bash
sudo journalctl -u heartbeatz-firstboot -f
```

---

## Step 4: Copy HeartBeatz Files & Bootstrap

From your laptop, copy the project to the MeLE:
```bash
scp -r HeartBeatz/ heartbeatz@<IP_ADDRESS>:~/
```

Then SSH in and run bootstrap:
```bash
ssh heartbeatz@<IP_ADDRESS>
sudo bash ~/HeartBeatz/system/bootstrap.sh
```

---

## Step 5: Reboot

```bash
sudo reboot
```

The MeLE boots → Docker starts → kiosk launches → HeartBeatz splash on
the 7" display. All automatic, no keyboard ever needed again.

---

## After Setup: All Management is Remote

```bash
# SSH in anytime
ssh heartbeatz@192.168.8.10

# Watch logs
sudo journalctl -u heartbeatz-kiosk -f

# Restart services
cd /opt/heartbeatz && docker compose restart

# Update code: scp new files, restart
scp -r HeartBeatz/server/ heartbeatz@192.168.8.10:~/HeartBeatz/
ssh heartbeatz@192.168.8.10 "cd /opt/heartbeatz && docker compose restart heartbeatz"
```

---

## Credentials Summary

| What | Value |
|---|---|
| Ubuntu user | `heartbeatz` |
| Ubuntu password | `heartbeatz` |
| SSH port | 22 (default) |
| Static IP | 192.168.8.10 |
| Router admin | http://192.168.8.1  |
| WiFi SSID | HeartBeatz |
| WiFi password | heartbeatz2026 |

**Change the passwords before any client demo!**

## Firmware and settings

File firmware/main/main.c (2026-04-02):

/**
 * ===========================================================================
 * HeartBeatz Sensor Node — Main Firmware
 * ===========================================================================
 * ESP32-S3 firmware for the HeartBeatz portable demo box. Each sensor node:
 *
 *   1. Connects to the HeartBeatz WiFi network (GL.iNet router)
 *   2. Registers a CSI callback to capture WiFi channel state information
 *   3. Packages CSI frames in ADR-018 binary format
 *   4. Streams frames via UDP to the MeLE N100 sensing server
 *   5. (Optional) Reads LD2410S mmWave radar data and appends to frames
 *   6. Reports status via built-in LED (breathing pattern = healthy)
 *   7. Supports OTA firmware updates from the HeartBeatz server
 *
 * Architecture:
 *   ┌─────────────────────────────────────────┐
 *   │  FreeRTOS Tasks                         │
 *   │  ├── main_task     — Init + orchestrate │
 *   │  ├── csi_task      — CSI callback + UDP │
 *   │  ├── radar_task    — LD2410S UART read  │
 *   │  ├── led_task      — Status LED control │
 *   │  └── ota_task      — OTA update check   │
 *   └─────────────────────────────────────────┘
 *
 * Build:   pio run
 * Flash:   pio run --target upload
 * Monitor: pio device monitor --baud 115200
 *
 * Configuration: see include/heartbeatz_config.h
 * Runtime overrides: stored in NVS namespace "heartbeatz"
 */

#include <stdio.h>
#include <string.h>
#include "freertos/FreeRTOS.h"
#include "freertos/task.h"
#include "freertos/event_groups.h"
#include "freertos/semphr.h"
#include "esp_system.h"
#include "esp_mac.h"
#include "esp_timer.h"
#include "esp_log.h"
#include "esp_event.h"
#include "esp_app_format.h"
#include "esp_ota_ops.h"
#include "esp_http_client.h"
#include "nvs_flash.h"

#include "heartbeatz_config.h"
#include "nvs_config.h"
#include "wifi_csi.h"
#include "udp_sender.h"
#include "led_status.h"
#include "radar_ld2410s.h"
#include "node_id.h"

/* ---------------------------------------------------------------------------
 * Constants
 * --------------------------------------------------------------------------- */

static const char *TAG = "heartbeatz";

/** FreeRTOS event group bits for system state tracking. */
#define WIFI_CONNECTED_BIT   BIT0
#define CSI_STREAMING_BIT    BIT1
#define RADAR_READY_BIT      BIT2
#define OTA_IN_PROGRESS_BIT  BIT3

/** Task stack sizes (bytes). Tuned for ESP32-S3 with PSRAM. */
#define CSI_TASK_STACK     8192
#define RADAR_TASK_STACK   4096
#define LED_TASK_STACK     2048
#define OTA_TASK_STACK     8192
#define NODE_ID_TASK_STACK 4096

/** Task priorities (higher number = higher priority). */
#define CSI_TASK_PRIO      10   /* Highest — real-time CSI streaming */
#define RADAR_TASK_PRIO     8   /* High — UART must not overflow */
#define LED_TASK_PRIO       2   /* Low — cosmetic only */
#define OTA_TASK_PRIO       3   /* Low — runs periodically */
#define NODE_ID_TASK_PRIO   2   /* Low — cosmetic LED blink */

/* ---------------------------------------------------------------------------
 * Globals
 * --------------------------------------------------------------------------- */

/** Shared event group for cross-task signalling. */
static EventGroupHandle_t s_system_events = NULL;

/** Runtime configuration loaded from NVS (or compile-time defaults). */
static heartbeatz_config_t s_config;

/** UDP sender handle (shared between CSI callback and radar task). */
static udp_sender_handle_t s_udp = NULL;

/** Latest radar reading (written by radar task, read by CSI callback). */
static radar_reading_t s_radar_reading = {0};
static SemaphoreHandle_t s_radar_mutex = NULL;

/* ---------------------------------------------------------------------------
 * Forward Declarations
 * --------------------------------------------------------------------------- */

static void csi_task(void *arg);
static void radar_task(void *arg);
static void led_task(void *arg);
static void ota_check_task(void *arg);

/* ---------------------------------------------------------------------------
 * Main Entry Point
 * --------------------------------------------------------------------------- */

void app_main(void)
{
    ESP_LOGI(TAG, "╔══════════════════════════════════════════╗");
    ESP_LOGI(TAG, "║  HeartBeatz Sensor Node v1.0.0           ║");
    ESP_LOGI(TAG, "║  WiFi CSI + Radar + OTA                  ║");
    ESP_LOGI(TAG, "╚══════════════════════════════════════════╝");

    /* --- Initialize NVS (required for WiFi + config storage) --- */
    esp_err_t ret = nvs_flash_init();
    if (ret == ESP_ERR_NVS_NO_FREE_PAGES ||
        ret == ESP_ERR_NVS_NEW_VERSION_FOUND) {
        /* NVS partition was truncated or format changed — erase and retry */
        ESP_LOGW(TAG, "NVS init failed (%s) — erasing and retrying", esp_err_to_name(ret));
        ESP_ERROR_CHECK(nvs_flash_erase());
        ESP_ERROR_CHECK(nvs_flash_init());
    } else {
        ESP_ERROR_CHECK(ret);
    }

    /* --- Load runtime configuration from NVS (falls back to compile-time defaults) --- */
    nvs_config_load(&s_config);
    ESP_LOGI(TAG, "Config: SSID=%s, server=%s:%d, CSI rate=%d Hz, radar=%s",
             s_config.wifi_ssid,
             s_config.server_ip,
             s_config.udp_port,
             s_config.csi_rate_hz,
             s_config.radar_enabled ? "ON" : "OFF");

    /* --- Create system event group --- */
    s_system_events = xEventGroupCreate();
    configASSERT(s_system_events);

    /* --- Create radar data mutex --- */
    s_radar_mutex = xSemaphoreCreateMutex();
    configASSERT(s_radar_mutex);

    /* --- Initialize default event loop (required for WiFi events) --- */
    ESP_ERROR_CHECK(esp_event_loop_create_default());

    /* --- Initialize LED status (starts breathing pattern immediately) --- */
    led_status_init(s_config.led_pin);
    led_status_set(LED_STATE_CONNECTING);

    /* --- Connect to WiFi and start CSI collection --- */
    ESP_LOGI(TAG, "Connecting to WiFi: %s (channel %d)", s_config.wifi_ssid, s_config.channel);
    hb_csi_config_t csi_cfg = {
        .ssid       = s_config.wifi_ssid,
        .password   = s_config.wifi_pass,
        .channel    = s_config.channel,
        .rate_hz    = s_config.csi_rate_hz,
        .events     = s_system_events,
        .connected_bit = WIFI_CONNECTED_BIT,
    };
    ESP_ERROR_CHECK(wifi_csi_init(&csi_cfg));

    /* --- Wait for WiFi connection (with timeout) --- */
    ESP_LOGI(TAG, "Waiting for WiFi connection...");
    EventBits_t bits = xEventGroupWaitBits(
        s_system_events, WIFI_CONNECTED_BIT,
        pdFALSE, pdTRUE,
        pdMS_TO_TICKS(30000)  /* 30 second timeout */
    );

    if (!(bits & WIFI_CONNECTED_BIT)) {
        ESP_LOGE(TAG, "WiFi connection timeout — restarting");
        led_status_set(LED_STATE_ERROR);
        vTaskDelay(pdMS_TO_TICKS(3000));
        esp_restart();
    }

    ESP_LOGI(TAG, "WiFi connected!");
    led_status_set(LED_STATE_IDLE);

    /* --- Initialize UDP sender --- */
    udp_sender_config_t udp_cfg = {
        .server_ip = s_config.server_ip,
        .port      = s_config.udp_port,
    };
    ESP_ERROR_CHECK(udp_sender_init(&udp_cfg, &s_udp));
    ESP_LOGI(TAG, "UDP sender ready → %s:%ld", s_config.server_ip, (long)s_config.udp_port);

    /* --- Launch FreeRTOS tasks --- */

    /* CSI streaming task (highest priority — real-time data) */
    xTaskCreatePinnedToCore(
        csi_task, "csi_task",
        CSI_TASK_STACK, NULL,
        CSI_TASK_PRIO, NULL,
        1  /* Pin to core 1 — keep core 0 for WiFi stack */
    );

    /* LD2410S radar task (if enabled) */
    if (s_config.radar_enabled) {
        xTaskCreatePinnedToCore(
            radar_task, "radar_task",
            RADAR_TASK_STACK, NULL,
            RADAR_TASK_PRIO, NULL,
            0  /* Core 0 — UART I/O */
        );
    }

    /* LED status task */
    xTaskCreate(led_task, "led_task", LED_TASK_STACK, NULL, LED_TASK_PRIO, NULL);

    /* OTA update check task */
    xTaskCreate(ota_check_task, "ota_task", OTA_TASK_STACK, NULL, OTA_TASK_PRIO, NULL);

    /* Node identification LED blink task */
    xTaskCreate(node_id_task, "node_id", NODE_ID_TASK_STACK,
                (void *)s_config.server_ip, NODE_ID_TASK_PRIO, NULL);

    ESP_LOGI(TAG, "All tasks launched — node operational");
    led_status_set(LED_STATE_STREAMING);
}

/* ---------------------------------------------------------------------------
 * CSI Streaming Task
 * ---------------------------------------------------------------------------
 * Waits for CSI frames from the WiFi callback, packages them in ADR-018
 * format (with optional radar data appended), and sends via UDP.
 *
 * The CSI callback (in wifi_csi.c) pushes raw frames into a FreeRTOS queue.
 * This task drains the queue, assembles the binary payload, and sends it.
 */
static void csi_task(void *arg)
{
    ESP_LOGI(TAG, "[CSI] Task started — streaming at ~%d Hz", s_config.csi_rate_hz);
    uint32_t frame_seq = 0;
    uint32_t error_count = 0;

    while (1) {
        /* Wait for a CSI frame from the callback queue (blocks up to 100ms) */
        wifi_csi_frame_t csi_frame;
        if (!wifi_csi_get_frame(&csi_frame, pdMS_TO_TICKS(100))) {
            /* No frame available — WiFi might be scanning or reconnecting */
            continue;
        }

        /* --- Build ADR-018 binary frame --- */
        /*
         * ADR-018 frame layout:
         *   [0..3]   Magic: 0xC5110001 (big-endian)
         *   [4..5]   Version: 0x0001
         *   [6..11]  Node MAC address (6 bytes)
         *   [12..15] Sequence number (little-endian)
         *   [16..19] Timestamp ms (little-endian)
         *   [20..21] CSI data length (little-endian)
         *   [22..N]  CSI amplitude/phase data
         *   [N+1]    Radar present flag (0 or 1)
         *   [N+2..]  Radar data (if flag = 1): state(1) + dist(2) + energy(1)
         */
        uint8_t frame_buf[1500];  /* Max UDP payload */
        size_t offset = 0;

        /* Magic */
        frame_buf[offset++] = 0xC5;
        frame_buf[offset++] = 0x11;
        frame_buf[offset++] = 0x00;
        frame_buf[offset++] = 0x01;

        /* Version */
        frame_buf[offset++] = 0x00;
        frame_buf[offset++] = 0x01;

        /* Node MAC */
        memcpy(&frame_buf[offset], csi_frame.mac, 6);
        offset += 6;

        /* Sequence number (LE32) */
        frame_buf[offset++] = (frame_seq >>  0) & 0xFF;
        frame_buf[offset++] = (frame_seq >>  8) & 0xFF;
        frame_buf[offset++] = (frame_seq >> 16) & 0xFF;
        frame_buf[offset++] = (frame_seq >> 24) & 0xFF;

        /* Timestamp (LE32) — milliseconds since boot */
        uint32_t ts = (uint32_t)(esp_timer_get_time() / 1000);
        frame_buf[offset++] = (ts >>  0) & 0xFF;
        frame_buf[offset++] = (ts >>  8) & 0xFF;
        frame_buf[offset++] = (ts >> 16) & 0xFF;
        frame_buf[offset++] = (ts >> 24) & 0xFF;

        /* CSI data length (LE16) */
        uint16_t csi_len = csi_frame.data_len;
        frame_buf[offset++] = (csi_len >> 0) & 0xFF;
        frame_buf[offset++] = (csi_len >> 8) & 0xFF;

        /* CSI data payload */
        if (offset + csi_len + 10 < sizeof(frame_buf)) {
            memcpy(&frame_buf[offset], csi_frame.data, csi_len);
            offset += csi_len;
        }

        /* --- Append radar data (if available) --- */
        if (s_config.radar_enabled && xSemaphoreTake(s_radar_mutex, 0) == pdTRUE) {
            if (s_radar_reading.valid) {
                frame_buf[offset++] = 1;  /* Radar present flag */
                frame_buf[offset++] = s_radar_reading.state;
                frame_buf[offset++] = (s_radar_reading.moving_dist >> 0) & 0xFF;
                frame_buf[offset++] = (s_radar_reading.moving_dist >> 8) & 0xFF;
                frame_buf[offset++] = s_radar_reading.moving_energy;
                frame_buf[offset++] = (s_radar_reading.stationary_dist >> 0) & 0xFF;
                frame_buf[offset++] = (s_radar_reading.stationary_dist >> 8) & 0xFF;
                frame_buf[offset++] = s_radar_reading.stationary_energy;
            } else {
                frame_buf[offset++] = 0;  /* No radar data */
            }
            xSemaphoreGive(s_radar_mutex);
        } else {
            frame_buf[offset++] = 0;  /* No radar data */
        }

        /* --- Send via UDP --- */
        esp_err_t err = udp_sender_send(s_udp, frame_buf, offset);
        if (err == ESP_OK) {
            frame_seq++;
            if (frame_seq % 500 == 0) {
                ESP_LOGI(TAG, "[CSI] Sent %lu frames (last %u bytes)", frame_seq, (unsigned)offset);
            }
        } else {
            error_count++;
            if (error_count % 100 == 1) {
                ESP_LOGW(TAG, "[CSI] Send error (%s), total errors: %lu",
                         esp_err_to_name(err), error_count);
            }
        }
    }
}

/* ---------------------------------------------------------------------------
 * LD2410S Radar Task
 * ---------------------------------------------------------------------------
 * Continuously reads UART data from the LD2410S 24GHz mmWave radar module.
 * Parses binary frames and updates the shared radar reading structure.
 * The CSI task reads this data and appends it to outgoing UDP frames.
 */
static void radar_task(void *arg)
{
    ESP_LOGI(TAG, "[Radar] Task started — UART pins TX=%ld RX=%ld @ %ld baud",
             (long)s_config.radar_tx_pin, (long)s_config.radar_rx_pin, (long)s_config.radar_baud);

    /* Initialize the LD2410S radar reader */
    radar_config_t radar_cfg = {
        .uart_num   = UART_NUM_1,
        .tx_pin     = s_config.radar_tx_pin,
        .rx_pin     = s_config.radar_rx_pin,
        .baud_rate  = s_config.radar_baud,
    };

    esp_err_t err = radar_ld2410s_init(&radar_cfg);
    if (err != ESP_OK) {
        ESP_LOGE(TAG, "[Radar] Init failed: %s", esp_err_to_name(err));
        vTaskDelete(NULL);
        return;
    }

    xEventGroupSetBits(s_system_events, RADAR_READY_BIT);
    ESP_LOGI(TAG, "[Radar] LD2410S initialized — reading frames");

    while (1) {
        radar_reading_t reading;
        if (radar_ld2410s_read(&reading, pdMS_TO_TICKS(200))) {
            /* Update the shared reading (protected by mutex) */
            if (xSemaphoreTake(s_radar_mutex, pdMS_TO_TICKS(10)) == pdTRUE) {
                s_radar_reading = reading;
                s_radar_reading.valid = true;
                xSemaphoreGive(s_radar_mutex);
            }
        }
    }
}

/* ---------------------------------------------------------------------------
 * LED Status Task
 * ---------------------------------------------------------------------------
 * Manages the on-board LED to indicate system state:
 *   - Fast blink:  Connecting to WiFi
 *   - Slow breathe: Connected, idle
 *   - Steady pulse: Streaming CSI data
 *   - Rapid flash:  Error state
 *   - Off:          OTA update in progress
 */
static void led_task(void *arg)
{
    ESP_LOGI(TAG, "[LED] Task started on GPIO %ld", (long)s_config.led_pin);

    while (1) {
        led_status_tick();
        vTaskDelay(pdMS_TO_TICKS(20));  /* ~50 Hz LED update rate */
    }
}

/* ---------------------------------------------------------------------------
 * OTA Update Check Task
 * ---------------------------------------------------------------------------
 * Periodically checks the HeartBeatz server for available firmware updates.
 * If an update is found, downloads it chunk-by-chunk, flashes it to the
 * inactive OTA partition, validates the image, and reboots.
 *
 * OTA endpoint: http://<server_ip>:8080/api/firmware/latest
 * The server returns:
 *   - 200 + binary:  new firmware available → download and flash
 *   - 304:           current firmware is up-to-date → no action
 *   - 404/5xx:       server not ready → retry later
 *
 * The node sends its current version in the X-Firmware-Version header so
 * the server can decide whether to serve an update.
 *
 * Partition layout (see partitions.csv):
 *   ota_0 (1.75MB) — app image slot A
 *   ota_1 (1.75MB) — app image slot B
 * ESP-IDF automatically selects the inactive slot for writing.
 */

/** Current firmware version — must match what the build system produces. */
#define HEARTBEATZ_FW_VERSION "1.0.0"

/** OTA HTTP read buffer size — 4KB is a good trade-off for ESP32 memory. */
#define OTA_BUF_SIZE 4096
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

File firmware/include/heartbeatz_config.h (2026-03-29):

/**
 * ===========================================================================
 * HeartBeatz Sensor Node — Compile-time Configuration
 * ===========================================================================
 * Default values for node behaviour. All can be overridden at runtime via
 * NVS (Non-Volatile Storage) using the sensing server's /api/v1/config
 * endpoint or the HeartBeatz setup wizard.
 *
 * NVS namespace: "heartbeatz"
 * See nvs_config.c in the RuView firmware for the full key reference.
 */

#ifndef HEARTBEATZ_CONFIG_H
#define HEARTBEATZ_CONFIG_H

/* ── WiFi ─────────────────────────────────────────────────────────────── */

/** SSID of the WiFi network for CSI sensing */
#ifndef HEARTBEATZ_WIFI_SSID
#define HEARTBEATZ_WIFI_SSID   "NETGEAR47"
#endif

/** WiFi password */
#ifndef HEARTBEATZ_WIFI_PASS
#define HEARTBEATZ_WIFI_PASS   "littletrain265"
#endif

/** WiFi channel — fixed channel improves CSI consistency (0 = auto) */
#ifndef HEARTBEATZ_CHANNEL
#define HEARTBEATZ_CHANNEL     3
#endif

/* ── Sensing Server ───────────────────────────────────────────────────── */

/** IP address of the MeLE N100 running the sensing server */
#ifndef HEARTBEATZ_SERVER_IP
#define HEARTBEATZ_SERVER_IP   "10.0.0.51"
#endif

/** UDP port for ADR-018 binary CSI frames */
#ifndef HEARTBEATZ_UDP_PORT
#define HEARTBEATZ_UDP_PORT    5005
#endif

/** Target CSI frame rate (Hz). 50 Hz is standard for vital sign detection. */
#ifndef HEARTBEATZ_CSI_RATE_HZ
#define HEARTBEATZ_CSI_RATE_HZ 50
#endif

/* ── LD2410S Radar (optional, connected via UART) ─────────────────────── */

/** Set to 1 to enable radar reading and include in UDP payload */
#ifndef HEARTBEATZ_RADAR_ENABLED
#define HEARTBEATZ_RADAR_ENABLED 0
#endif

/** UART TX pin connected to LD2410S RX */
#ifndef HEARTBEATZ_RADAR_TX_PIN
#define HEARTBEATZ_RADAR_TX_PIN  17
#endif

/** UART RX pin connected to LD2410S TX */
#ifndef HEARTBEATZ_RADAR_RX_PIN
#define HEARTBEATZ_RADAR_RX_PIN  18
#endif

/** LD2410S baud rate (fixed by module) */
#ifndef HEARTBEATZ_RADAR_BAUD
#define HEARTBEATZ_RADAR_BAUD    256000
#endif

/* ── LED ──────────────────────────────────────────────────────────────── */

/** Status LED GPIO pin (built-in on most ESP32-S3 DevKits) */
#ifndef HEARTBEATZ_LED_PIN
#define HEARTBEATZ_LED_PIN       48
#endif

/* ── ADR-018 Frame Format ─────────────────────────────────────────────── */

/** Magic bytes identifying a HeartBeatz CSI frame */
#define HEARTBEATZ_FRAME_MAGIC   0xC5110001

/** Frame header size (bytes): magic(4) + version(2) + node_id(6) + seq(4) + ts(4) */
#define HEARTBEATZ_HEADER_SIZE   20

/* ── Power Management ─────────────────────────────────────────────────── */

/**
 * Sleep between CSI callbacks to save battery.
 * Set to 0 for continuous operation (mains-powered demo).
 * Set to 1 for battery-optimised mode (reduces rate to ~10 Hz).
 */
#ifndef HEARTBEATZ_POWER_SAVE
#define HEARTBEATZ_POWER_SAVE    0
#endif

#endif /* HEARTBEATZ_CONFIG_H */

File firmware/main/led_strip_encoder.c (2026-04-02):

/**
 * led_strip_encoder.c — RMT encoder for WS2812 addressable LEDs.
 * Adapted from ESP-IDF example (Apache 2.0 license, Espressif Systems).
 */

#include "esp_check.h"
#include "led_strip_encoder.h"

static const char *TAG = "led_encoder";

typedef struct {
    rmt_encoder_t base;
    rmt_encoder_t *bytes_encoder;
    rmt_encoder_t *copy_encoder;
    int state;
    rmt_symbol_word_t reset_code;
} rmt_led_strip_encoder_t;

static size_t rmt_encode_led_strip(rmt_encoder_t *encoder, rmt_channel_handle_t channel,
                                    const void *primary_data, size_t data_size,
                                    rmt_encode_state_t *ret_state)
{
    rmt_led_strip_encoder_t *led_enc = __containerof(encoder, rmt_led_strip_encoder_t, base);
    rmt_encoder_handle_t bytes_enc = led_enc->bytes_encoder;
    rmt_encoder_handle_t copy_enc = led_enc->copy_encoder;
    rmt_encode_state_t session_state = RMT_ENCODING_RESET;
    rmt_encode_state_t state = RMT_ENCODING_RESET;
    size_t encoded_symbols = 0;

    switch (led_enc->state) {
    case 0: /* Send GRB pixel data */
        encoded_symbols += bytes_enc->encode(bytes_enc, channel, primary_data, data_size, &session_state);
        if (session_state & RMT_ENCODING_COMPLETE) {
            led_enc->state = 1;
        }
        if (session_state & RMT_ENCODING_MEM_FULL) {
            state |= RMT_ENCODING_MEM_FULL;
            goto out;
        }
    /* fall-through */
    case 1: /* Send reset code */
        encoded_symbols += copy_enc->encode(copy_enc, channel, &led_enc->reset_code,
                                             sizeof(led_enc->reset_code), &session_state);
        if (session_state & RMT_ENCODING_COMPLETE) {
            led_enc->state = RMT_ENCODING_RESET;
            state |= RMT_ENCODING_COMPLETE;
        }
        if (session_state & RMT_ENCODING_MEM_FULL) {
            state |= RMT_ENCODING_MEM_FULL;
            goto out;
        }
    }
out:
    *ret_state = state;
    return encoded_symbols;
}

static esp_err_t rmt_del_led_strip_encoder(rmt_encoder_t *encoder)
{
    rmt_led_strip_encoder_t *led_enc = __containerof(encoder, rmt_led_strip_encoder_t, base);
    rmt_del_encoder(led_enc->bytes_encoder);
    rmt_del_encoder(led_enc->copy_encoder);
    free(led_enc);
    return ESP_OK;
}

static esp_err_t rmt_led_strip_encoder_reset(rmt_encoder_t *encoder)
{
    rmt_led_strip_encoder_t *led_enc = __containerof(encoder, rmt_led_strip_encoder_t, base);
    rmt_encoder_reset(led_enc->bytes_encoder);
    rmt_encoder_reset(led_enc->copy_encoder);
    led_enc->state = RMT_ENCODING_RESET;
    return ESP_OK;
}

esp_err_t rmt_new_led_strip_encoder(const led_strip_encoder_config_t *config,
                                     rmt_encoder_handle_t *ret_encoder)
{
    esp_err_t ret = ESP_OK;
    rmt_led_strip_encoder_t *led_enc = NULL;
    ESP_GOTO_ON_FALSE(config && ret_encoder, ESP_ERR_INVALID_ARG, err, TAG, "invalid argument");
    led_enc = calloc(1, sizeof(rmt_led_strip_encoder_t));
    ESP_GOTO_ON_FALSE(led_enc, ESP_ERR_NO_MEM, err, TAG, "no mem for led strip encoder");

    led_enc->base.encode = rmt_encode_led_strip;
    led_enc->base.del = rmt_del_led_strip_encoder;
    led_enc->base.reset = rmt_led_strip_encoder_reset;

    /* WS2812 bit timing */
    rmt_bytes_encoder_config_t bytes_cfg = {
        .bit0 = {
            .level0 = 1,
            .duration0 = 0.3 * config->resolution / 1000000,  /* T0H = 0.3us */
            .level1 = 0,
            .duration1 = 0.9 * config->resolution / 1000000,  /* T0L = 0.9us */
        },
        .bit1 = {
            .level0 = 1,
            .duration0 = 0.9 * config->resolution / 1000000,  /* T1H = 0.9us */
            .level1 = 0,
            .duration1 = 0.3 * config->resolution / 1000000,  /* T1L = 0.3us */
        },
        .flags.msb_first = 1,  /* WS2812 bit order: G7..G0 R7..R0 B7..B0 */
    };
    ESP_GOTO_ON_ERROR(rmt_new_bytes_encoder(&bytes_cfg, &led_enc->bytes_encoder), err, TAG, "create bytes encoder failed");

    rmt_copy_encoder_config_t copy_cfg = {};
    ESP_GOTO_ON_ERROR(rmt_new_copy_encoder(&copy_cfg, &led_enc->copy_encoder), err, TAG, "create copy encoder failed");

    /* Reset code: 50us low */
    uint32_t reset_ticks = config->resolution / 1000000 * 50 / 2;
    led_enc->reset_code = (rmt_symbol_word_t) {
        .level0 = 0, .duration0 = reset_ticks,
        .level1 = 0, .duration1 = reset_ticks,
    };

    *ret_encoder = &led_enc->base;
    return ESP_OK;

err:
    if (led_enc) {
        if (led_enc->bytes_encoder) rmt_del_encoder(led_enc->bytes_encoder);
        if (led_enc->copy_encoder) rmt_del_encoder(led_enc->copy_encoder);
        free(led_enc);
    }
    return ret;
}

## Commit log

2026-03-29 feat: floor plan upload, L-shaped room map, per-node vitals, calibration UI
    Major changes to the HeartBeatz sensing platform:
    - Room map: Updated from simple rectangle to actual floor plan layout
    (Zithoek/Eethoek/Keuken with Inkomhal cutout), furniture hints, zone labels
    - Floor plan setup wizard: 3-step UI flow to upload plan image, draw room
    outline polygon, and place sensor nodes via drag-and-drop
    - Server API: Added POST/GET/DELETE /api/floorplan for image storage,
    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
    [main_box_assembly.step, main_box_base.step, main_box_lid.step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]
2026-03-29 feat: V2 sensor node enclosure for SparkleIoT XH-S3E + SMA antenna + TECNOIOT UPS
    Parametric CadQuery enclosure design updated for actual hardware:
    - SparkleIoT XH-S3E ESP32-S3 N16R8 (55x25.5x9mm) with U.FL→SMA pigtail
    - TECNOIOT 18650 UPS HAT (90x22x18mm) with single 18650 cell
    - SMA panel-mount bulkhead through top wall for external dipole antenna
    - Two-compartment vertical layout: UPS below, ESP32 above
    - Snap-fit front cover, wall-mount keyhole slots
    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
2026-03-31 feat: Sprint 1 Day 1 — complete feature extraction, ground truth, admin, sensors
    Multi-agent development system (3 workers + reviewer + architect) built:
    Signal Processing (Worker Alpha):
    - Subcarrier grouping, phase extraction, Doppler FFT
    - Statistical features (skewness, kurtosis, entropy, IQR)
    - Correlation matrix with eigenvalue analysis
    - Frame quality scoring, feature serialization (JSON+CSV)
    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
2026-04-02 feat: GL.iNet network config, node ID blink, UI tuning & CSI bridge v3
    - Switch all ESP32 nodes to GL.iNet portable router (SSID: heartbeatz)
    - Add WS2812 RGB LED node identification: blinks node number on boot
    using RMT-based led_strip encoder (GPIO 48, ESP-IDF 5.x compatible)
    - CSI bridge: add /api/nodes/identify endpoint with firstSeen ordering
    - UI: tuning sliders, node rename, presets, room map fixes
    - Server: force demo mode off, proxy routes for CSI bridge API
    [led_status.c, led_strip_encoder.c, main.c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]
